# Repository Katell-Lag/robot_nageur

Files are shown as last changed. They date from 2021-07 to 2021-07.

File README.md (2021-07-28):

# Robot_nageur
Ce dépôt rassemble les codes et les documents réalisés lors du stage ingénieur d'Anna Agobian et Katell Lagattu.

Vous pourrez retrouver l'ensemble des scripts python et C, les fichiers des pièces 3D, datasheet et documentations utilisées.

Un README a été créé pour chacun des dossiers afin d'ajouter une description plus détaillée des documents disponibles.

## Décomposition du robot 

Ce robot se compose de la manière suivante : un buste (stockant l’ensemble du matériel électronique : cartes, batteries etc.) composé de 2 bras, équipé chacun de 3 articulations (une épaule, une rotation biceps et un coude), et de 2 jambes, équipée chacune d’un unique moteur. 

Au total, le robot sera composé de 9 tubes étanches (3 pour chaque bras, 1 pour le buste et 1 pour chaque jambe), d’une dizaine de cartes électroniques, d’une unique batterie. Parmi les cartes électroniques on retrouvera soit une unique BeagleBone Blue accompagnée de 3 ESC pour générer le signal PWM de nos BLDC, soit une raspberry PI3 (ou plusieurs suivant les SPI disponibles) accompagnée de 3 cartes (1pour chaque moteur du bras) trinamic TMC4671+TMC6100-BOB pour réaliser la boucle fermée et générer le signal PWM des BLDC. 
En plus de cela sera rajouté des IMU (centrales inertielles) aux biceps, avant-bras et jambes afin de s’assurer du mouvement exécuté. Elles seront alors accompagnées d’une carte STM32 permettant de traiter leurs données et de les communiquer à la carte mère.

## Aspect général du robot

Réaliser ce robot doit être fait en diverses étapes très distinctes. En effet, avant de partir sur sa construction et le tester dans l'eau il faut vérifier son mouvement, gérer l'emmêlement des fils électriques etc.
Ainsi nous avions donc défini cet aspect global de réalisation :

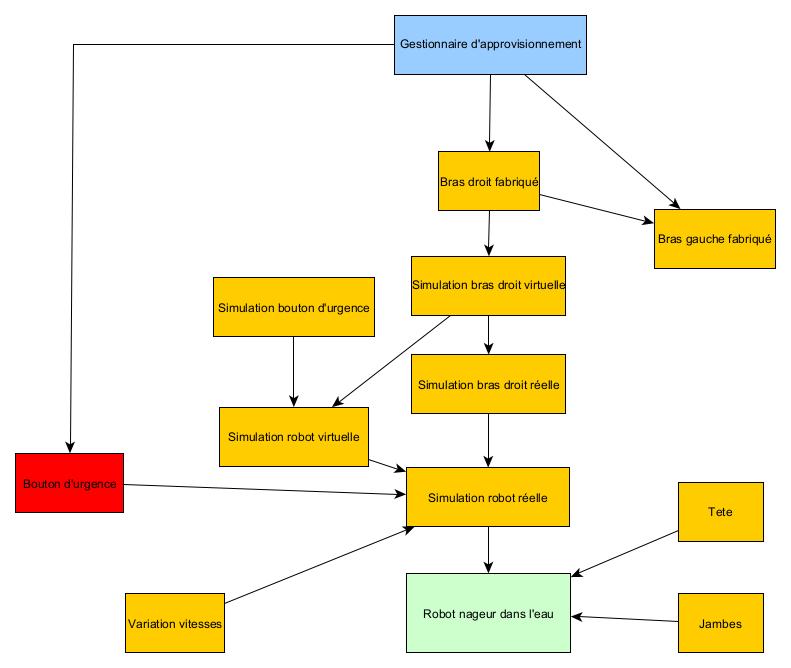
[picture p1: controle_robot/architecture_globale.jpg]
aspect général


Nous avons donc actuellement réaliser le bras gauche, simuler le bras, le robot entier en virtuel et réaliser le bouton d'urgence. Nous en étions à la réalisation du bras gauche en réel.

Pour tout renseignement supplémentaire contactez nous via les emails suivants :
##### anna.agobian@etu.umontpellier.fr
##### katell.lagattu@ensta-bretagne.org

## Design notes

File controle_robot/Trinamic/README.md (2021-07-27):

DOCUMENTATION TRINAMIC

- Avec la TMC6100-EVAL-KIT (kit de développement, utilisation de l'IDE de Trinamic)
- Avec la TMC4671+TMC6100-BOB (tentatives de connexion en SPI avec une Raspberry Pi3)

LIENS

- Github Trinamic: https://github.com/trinamic
- Site de Trinamic: https://www.trinamic.com/support/software/
- Blog de Trinamic avec des tutos: https://blog.trinamic.com/
- Chaîne youtube de Trinamic: https://www.youtube.com/user/TrinamicMC

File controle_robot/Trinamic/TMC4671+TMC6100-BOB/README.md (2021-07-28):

# UTILISATION DE LA TMC4671+TMC6100-BOB

La carte  trinamic TMC4671+TMC6100-BOB est une carte de développement permettant à l'utilisateur de prototyper des applications directes à ses moteurs. Cette carte permet de contrôler un moteur, de récupérer les données de 2 encodeurs et surtout de réaliser une boucle fermée. 
En effet, l'avantage principal de ces cartes est leur contrôle en boucle fermée. Ceci permet d'obtenir un système plus performant, plus stable et optimal: le retour des encodeurs permet d'asservir le système via un correcteur PID et d'assurer une stabilité.
Ces cartes permettent aussi de contrôler les moteurs par la commande FOC(Field-Oriented Control)- soit contrôle à flux orienté-. 

### Commande FOC

En effet, cette commande FOC- appelée également "commande vectorielle"- permet de garder une précision continue des commandes envoyées, notamment pour les moteurs BLDC (BrushLess Direct Courant). Pour se faire, c'est à partir de la consigne de vitesse du moteur que le flux et le couple nécessaire sont calculés et qu'ensuite les courants requis sont déduits. 

La commande FOC est composée de deux forces Q (quadrature) et D (direct), perpendiculaire et parallèle à l'axe des pôles du rotor. 

### Synoptique



c: type de connexion     p : nombre de ports/fils envisagés

### Ce dossier décrit nos tests pour faire fonctionner le bus SPI entre Raspberry et Trinamic.

#### REMARQUE PRELIMINAIRE:

Pour accéder à la Raspberry que nous avons utilisée, et qui contient tous nos fichiers tests:

Via un écran, aller dans /etc/wpa_supplicant/wpa_supplicant.conf et rentrer un réseau wifi et son mot de passe pour se connecter via ssh. 

user: pi

mdp: raspberry

#### BRANCHEMENTS: 

voir schéma.

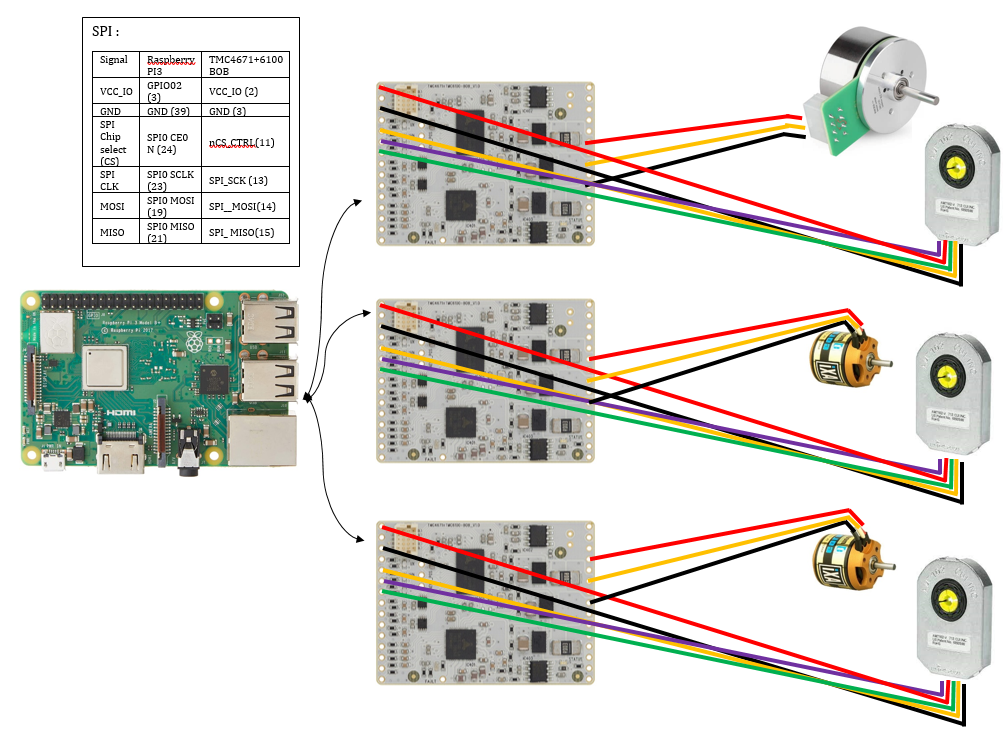
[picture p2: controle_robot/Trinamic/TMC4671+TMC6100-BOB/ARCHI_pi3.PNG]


#### CONTEXTE:

Pour contrôler les moteurs avec la TMC4671+TMC6100-BOB, il faut d'une part envoyer les bons registres à la carte, et d'autre part configurer correctement la communication SPI. Nous n'avons pas réussi à faire fonctionner le SPI, mais ce dossier rassemble nos pistes.

#### REGISTRES:

Les registres que nous avons utilisés sont: 
  - Ceux que nous avons exporté du TMCL-IDE (voir https://github.com/Katell-Lag/robot_nageur/blob/main/controle_robot/Trinamic/TMC6100-EVAL-KIT/20210706_10.24.59_TMC4671-EVAL_Settings_V1.c)
  - Ceux qui sont dans le Pytrinamic et qui fonctionnaient via USB (voir https://github.com/trinamic/PyTrinamic/blob/master/PyTrinamic/examples/evalboards/TMC4671/TMC4671_eval_BLDC_open_loop.py)

#### COMMUNICATION SPI:

Voir TMCAPI_EXAMPLE et TMCAPI_EXAMPLE2.

Ces codes sont inspirés du tuto: http://blog.trinamic.com/2018/02/19/stepper-motor-with-tmc5160/

Ce tuto explique comment relier une Raspberry Pi3 à une TMC5160-BOB.

Nous avons essayé d'adapter le code de différentes manières pour faire fonctionner la liaison avec notre carte, mais sans succès.

#### NOTES SUR LA COMMUNICATION SPI:

- Nous utilisons la librairie bcm2835 pour configurer le SPI.

- Nous avons une incertitude sur les modes des PIN (HIGH ou LOW). De plus, la carte du tuto ne possède pas les mêmes PIN que la nôtre. Par exemple, nous avons supposé qu'il ne fallait pas se soucier du CLK.

- Concernant la fonction tmc4671_readwriteByte, elle doit être présente si l'on utilise la dernière version du TMC-API. Nous ne savons pas si elle est nécessaire dans notre cas.

- Les fonctions définies dans le TMC_SPI.c sont les fonctions permettant de transmettre les données en SPI, plus précisément d'écrire dans les registres de la carte via SPI.

- Nous avons essayé de lire des données provenant de la carte avec tmc4671_ReadInt mais sans succès. Il semble que la liaison ne se fasse pas.

- Après avoir réalisé des tests grâce à un loopback test avec l'API spidev, nous avons conclu que le problème n'était pas la Raspberry elle-même: https://www.raspberrypi.org/documentation/hardware/raspberrypi/spi/README.md

- A l'oscilloscope, nous avons également pu observer que des trames étaient bien envoyées de la Raspberry vers la Trinamic. Nous pensons donc que la Trinamic ne parvient pas à interpréter ces trames.

#### AUTRES METHODES:

Nous avons aussi utilisé d'autres méthodes qui n'ont pas fonctionné non plus, peut-être parce que les cartes utilisées dans ses librairies ne sont pas les mêmes: voir test_levref (à partir de https://github.com/trinamic/PyTrinamic/commit/4e6927a0448545c5d8767285cda3d14c63dbb35c) et tripipy (à partir de https://github.com/pootle/tripipy).

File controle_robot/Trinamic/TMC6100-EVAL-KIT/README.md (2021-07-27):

# UTILISATION DE LA TMC6100-EVAL-KIT (VIA TMCL-IDE ET CODE PYTHON).

## PRESENTATION:

La TMC6100-EVAL-KIT est composée d'un microcontrôleur Landungsbrücke, deux cartes de liaisons Eselsbrücke, une carte "motion controller" TMC4671-EVAL et une carte driver TMC6100-EVAL. L'intérêt d'utiliser une telle carte par rapport à une BeagleBone est qu'elle est capable de contrôler un moteur BLDC en boucle fermée, aussi bien en couple qu'en position.

## TMCL-IDE:

On accède au TMCL-IDE via usb. Il se télécharge à partir du lien suivant : https://www.trinamic.com/support/software/tmcl-ide/ 

Cet IDE a été conçu par TRINAMIC afin de simuler à partir d'une fenêtre "*wizard*" le comportement du moteur en sortie. En effet, il permet de visualiser en direct le comportement du BLDC en fonction des encodeurs, ou "sensors hall", de modifier les paramètres PI du correcteur et également ceux du moteur lui-même. Il est également possible de changer le firmware de la Landungsbrücke afin d'y entrer par défault les paramètres souhaités. Cependant, nous n'avons actuellement pas réussi à réaliser cette action correctement.

*EXEMPLE : Pour faire tourner un des moteurs BLDC: aller dans Wizards et entrer les paramètres visibles dans les captures d'écran du dossier robot_nageur/controle_robot/Trinamic/TMC6100-EVAL-KIT/Setup
La boucle fermée fonctionne, ainsi que le FOC (Field Oriented Control).* 

## BRANCHEMENTS: 

voir schéma
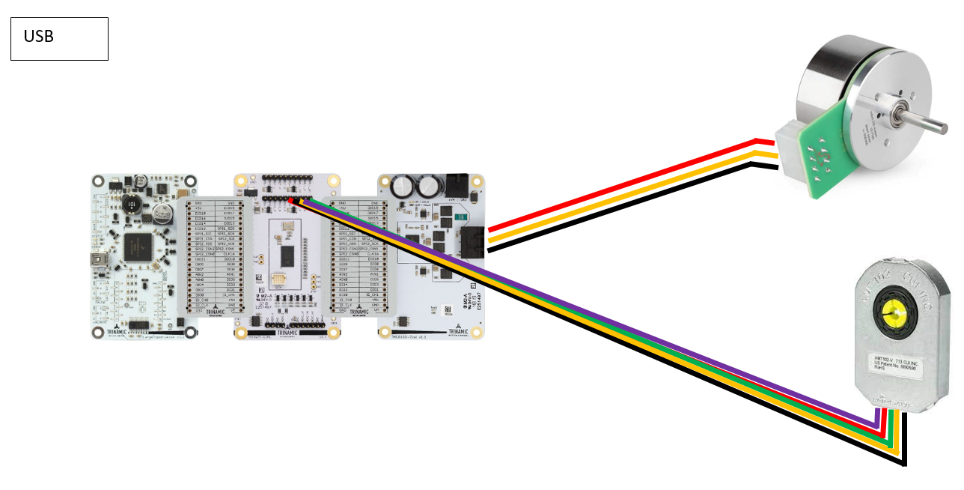
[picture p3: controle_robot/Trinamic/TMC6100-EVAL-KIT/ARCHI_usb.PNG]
branchement usb


## DOCUMENTS UTILES

* Manual : https://www.trinamic.com/fileadmin/assets/Support/Software/TMCL_reference.pdf

* Tuto de Trinamic pour la configuration Wizard: https://blog.trinamic.com/2020/02/25/driving-a-linear-stage-with-the-tmc4671/

* Tuto en vidéo de la configuration Wizard: https://www.youtube.com/watch?v=g2BHEdvW9bU&t=32s

## LIEN GITHUB VERS CODE PYTHON FONCTIONNEL:

Sans passer par l'IDE mais en exécutant un code python avec une liaison USB, nous arrivons à faire tourner le moteur en boucle ouverte.
Ce code fonctionne avec une connexion usb, soit entre la Trinamic et un PC, soit entre la Trinamic et une Raspberry.

https://github.com/trinamic/PyTrinamic/blob/master/PyTrinamic/examples/evalboards/TMC4671/TMC4671_eval_BLDC_open_loop.py

###### NOTES:

- Si le voyant rouge de la carte s'allume, double cliquer sur Landunsbruecke puis décocher et recocher "enable drivers". Pour éviter qu'il s'allume, il faut décocher cette case avant d'alimenter les moteurs, puis la recocher.
- Nous avons essayé de changer directement le firmware en suivant le tuto: https://blog.trinamic.com/2020/02/28/driving-a-linear-stage-with-the-tmc4671-firmware-adaptation/ mais cela a fait planter la carte. Si jamais cela arrive, il suffit de court-circuiter id_clk et id_ch0, puis de redémarrer/rebrancher la carte. On peut alors remettre l'ancien firmware disponible sur le site de Trinamic.
- Le "direct mode" qui permet de contrôler le moteur sans passer par le Wizard fonctionne: https://blog.trinamic.com/2020/02/26/driving-a-linear-stage-with-the-tmc4671-controller-tuning/

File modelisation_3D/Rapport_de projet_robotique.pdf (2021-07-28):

Ecole Polytechnique Universitaire de Montpellier, Département micro-électronique et automatique
Place Eugène Bataillon, 34095 Montpellier | 1 / 30

## ROBOTIQUE MOBILE S8 – MEA4

## Année scolaire 2020-2021

## ″Projet : Modélisation, conception et réalisation d’un robot nageur″

Etudiants : Anna AGOBIAN, Tatiana DEWILDEMAN,

## Théo LEMAIRE, Paul MASSON

## Encadrants : René ZAPATA, Éric DUBREUIL, Lionel LAPIERRE

SOMMAIRE

## 1 INTRODUCTION

Ce document est un rapport du travail effectué dans le cadre des projets de robotiques mobiles au S8 en MEA4.

### 1.1 Contexte

Le but de ce projet est de développer un robot humanoïde nageur (crawl et/ou papillon). Celui-ci doit être capable de se déplacer et de s’orienter dans un environnement ouvert et agité comme la mer. Afin de s’orienter, celui-ci comportera une tête, déjà développée, utilisant un algorithme de perception des bouées jaunes.

### 1.2 Attentes

Modélisation, conception et réalisation d’un robot nageur. Le travail consiste à étudier les modèles de nage d’un robot nageur (crawl et/ou papillon), de réaliser des simulations (à partir d’outils existants), de réaliser une maquette de bras, d’effectuer une recherche internet sur des moteurs qui pourraient être adéquats et enfin, de réaliser un robot réel (échelle de 1/2 ou 1 à préciser).

## 2 MODELISATION

### 2.1 Adaptation du bras humain

Le bras humain est constitué de 5 degrés de liberté :
- Rotation principale de l’épaule a1
- Écartement de l’épaule du corps a2
- Rotation axiale de l’épaule a3
- Pliement du coude a4
- Rotation axiale de l’avant-bras a5

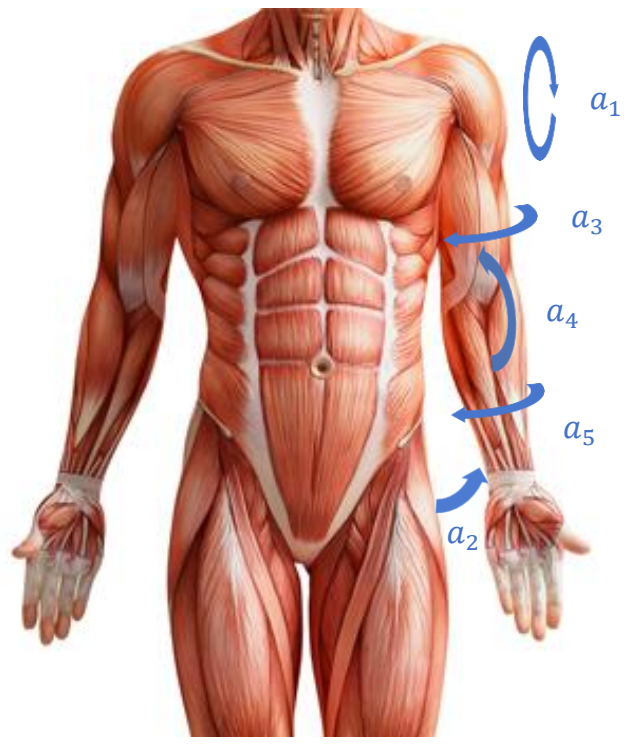
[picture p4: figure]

Figure 1: Illustration des degrés de liberté du bras humain

A chacun de ces degrés de liberté est associé une articulation, générant une complexité de modélisation non négligeable. Cependant, lors d’un mouvement de nage tel que le crawl, seuls les articulations a1, a3 et a4 sont indispensables. Par soucis de simplicité, nous nous limiterons donc à ces 3 degrés de liberté.

### 2.2 Détermination du mouvement

Afin de déterminer le mouvement du bras lors de la nage du crawl, nous utilisons le simulateur MATLAB, nommé KynProfile, permettant de contrôler un bras simplifié aux 3 degrés de libertés précédemment évoqués.

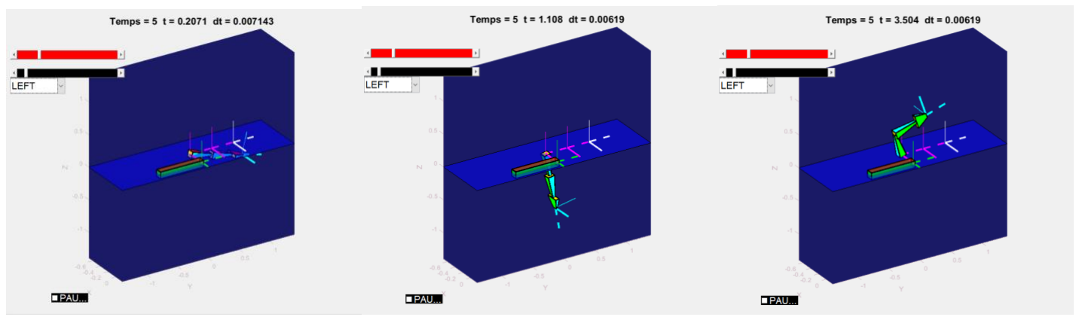
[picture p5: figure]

Figure 2: Illustrations du simulateur KynProfile

Ce simulateur prend en entrée les commandes angulaires de chaque articulation. Afin de former ces commandes, nous utilisons un 2ième simulateur, nommé Deform_Splines.

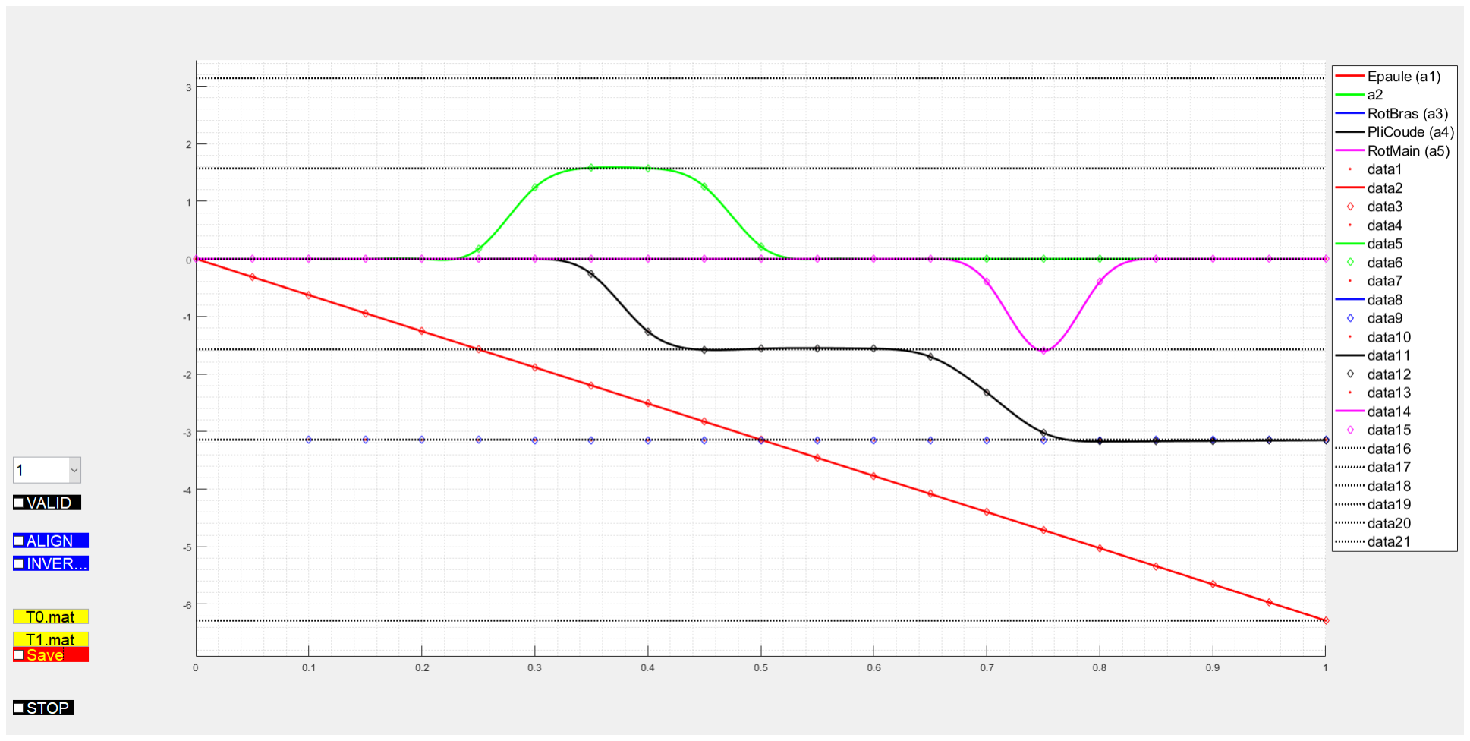
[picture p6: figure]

Figure 3: Illustration du simulateur Deform_Splines

Celui-ci nous permet de manier les trajectoires angulaires de chaque articulation. L’axe des abscisses représente une période, ici un mouvement de crawl, tandis que l’axe des ordonnées représente la position angulaire de l’articulation. Il est donc important que chacune des articulations en x = 1 se retrouve à sa position initiale ± 2π pour garantir la continuité du mouvement entre chaque période.

Grâce à ces 2 simulateurs, nous avons décomposé un mouvement de crawl en un enchaînement de mouvements élémentaires et faisables avec les 3 articulations :

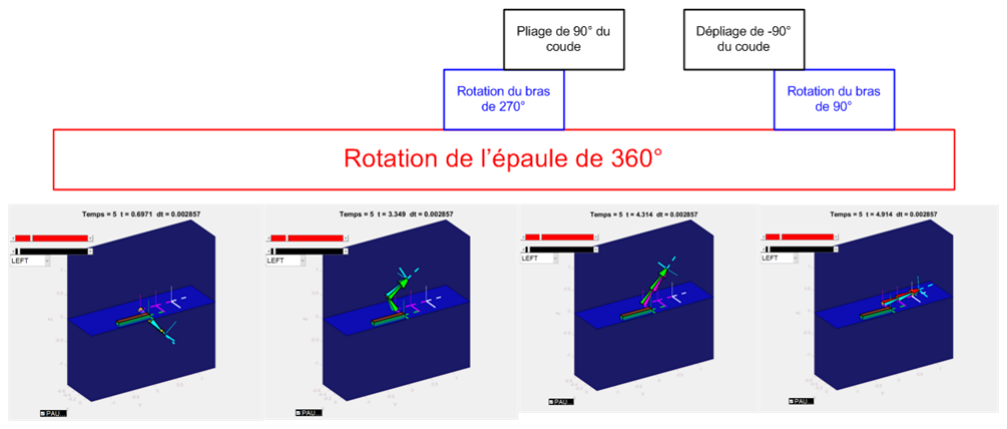
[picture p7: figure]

Figure 4: Enchainement des mouvements lors du crawl

Cet enchaînement se traduit par les trajectoires angulaires suivantes :

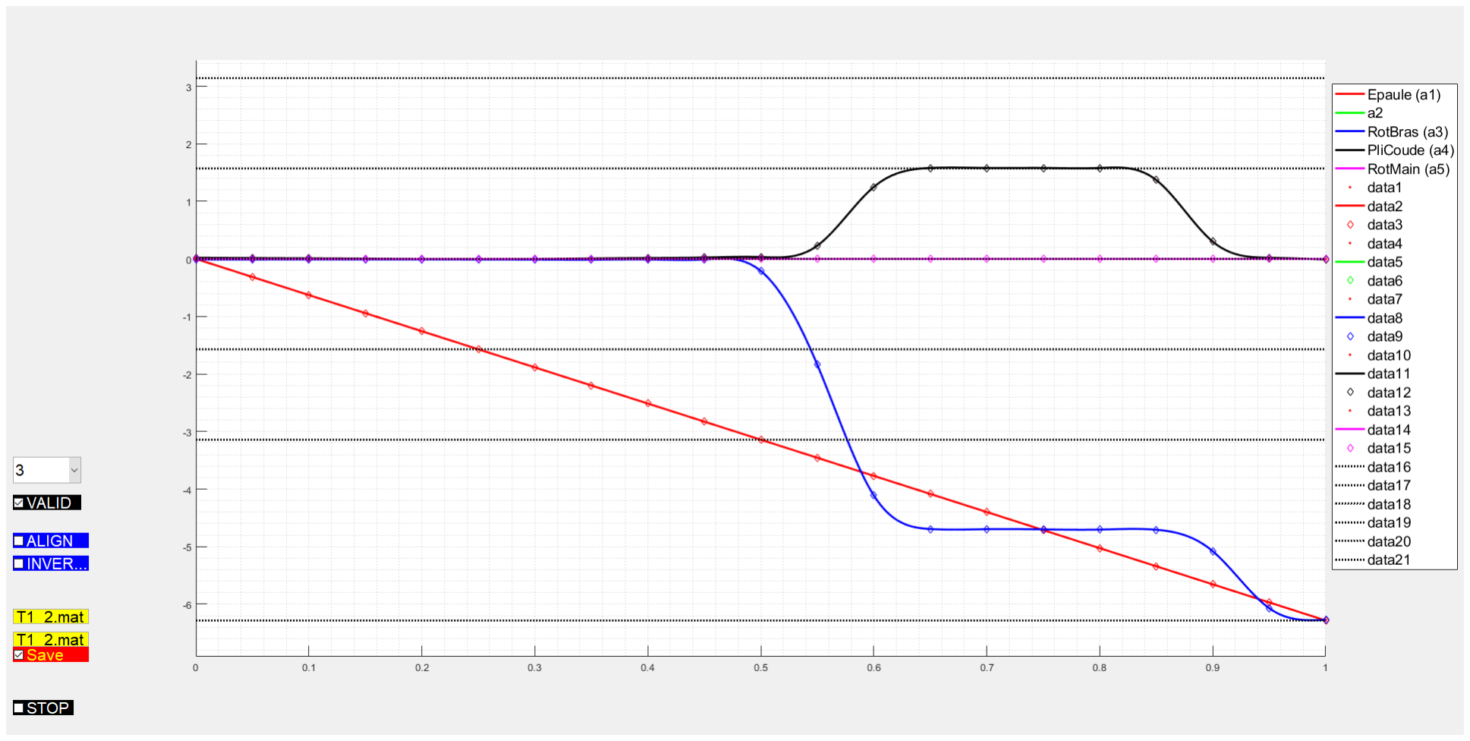
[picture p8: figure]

Figure 5: Trajectoires angulaires de a1, a3 et a4 lors d’un mouvement de crawl

### 2.3 Extraction des commandes et choix du type des moteurs

Une fois le mouvement du crawl vérifié et validé sur simulateur, nous avons pu extraire les trajectoires de chacune des articulations et en déduire les moteurs que nous allons utiliser :
- Rotation continue sur a1 Þ utilisation d’un moteur CC avec un encodeur pour asservir en position.
- Enchaînements de rotations de 90° ou 270° sur a3 Þ utilisation d’un moteur CC avec un encodeur pour asservir en position.
- Enchaînements de rotations de 90° dans les 2 sens sur a4 Þ utilisation d’un servo moteur.

Toutes les positions des 3 trajectoires ont été enregistrées dans un fichier CSV afin de pouvoir les utiliser avec l’algorithme de commande.

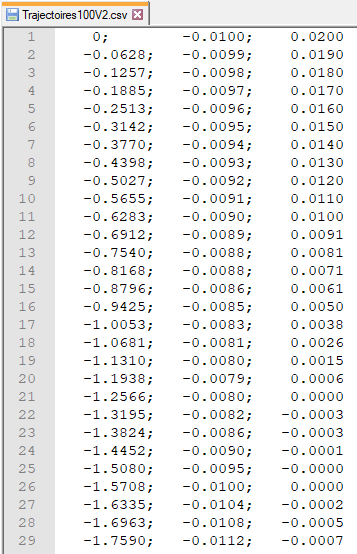
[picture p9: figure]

Figure 6: Début du fichier CSV des positions

### 2.4 Réalisation de la maquette

Afin de confirmer notre modèle théorique, nous avons réalisé une maquette du bras. Pour correspondre au modèle simplifié précédemment explicité, celle-ci est constituée de 4 parties :
- Un buste
- Une épaule
- Un bras
- Un avant-bras avec une main

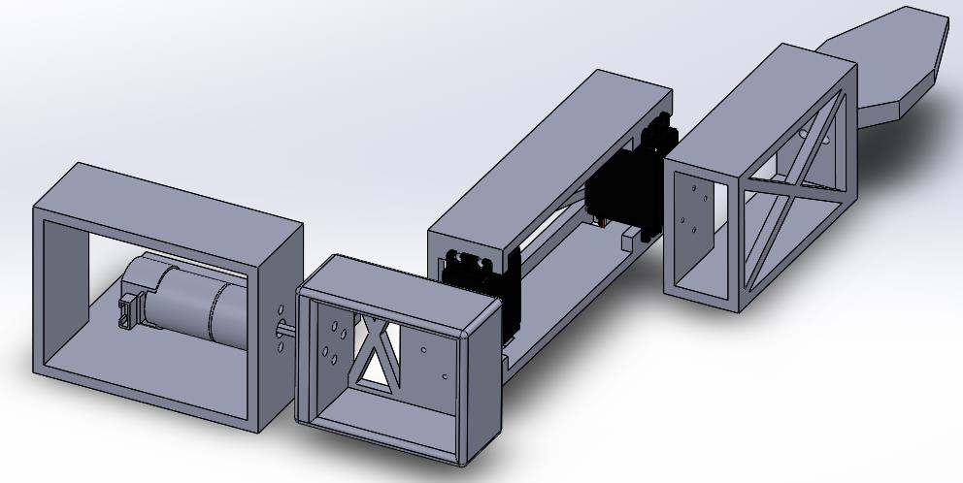
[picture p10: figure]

Figure 7: Maquette du bras – 1

ère version

La Figure 7 représente la première version de la maquette. Celle-ci est constituée d’un moteur CC avec encodeur et de 2 servos moteurs. Cependant, lors des tests avec celle-ci, nous nous sommes rendu compte que l’articulation a3 devait pouvoir faire une rotation de 360°. En effet, pour éviter que les fils des moteurs ne s’enroulent autour du bras lors de son mouvement, nous sommes dans l’obligation d’effectuer une rotation complète sur a3, mouvement impossible pour un bras humain. Or, un servo moteur est limité à 180°. C’est donc pour cette raison que nous avons choisi d’utiliser un moteur CC à cette position.

Une fois cette contrainte identifiée, les pièces de l’épaule et du bras ont été modifiées pour donner le modèle suivant :

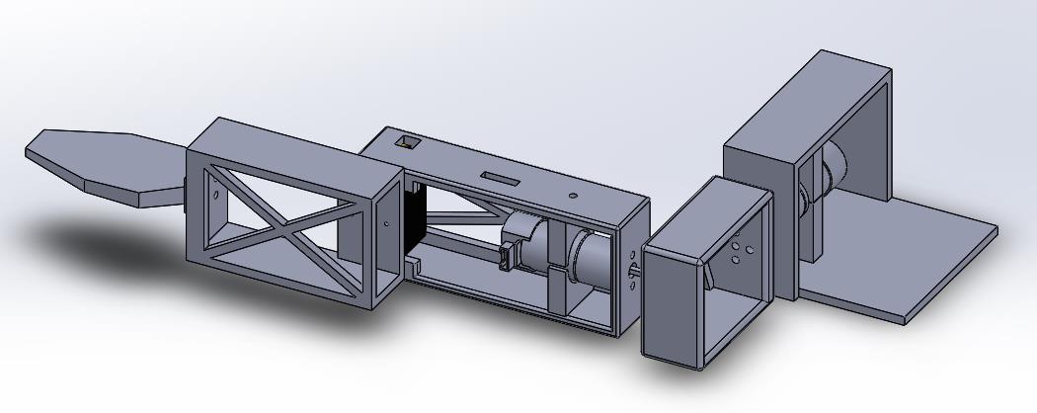
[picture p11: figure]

Figure 8: Maquette du bras – 2

ième version

Etant donné le faible couple que possède notre moteur CC responsable de la rotation de l’épaule (articulation a1), nous avons été contraints de rajouter un jeu d’engrenages. Ainsi, la liaison entre le buste et l’épaule se fait maintenant grâce à 2 engrenages (80 dents et 16 dents) multipliant le couple par 5.

### 2.5 Modélisation du robot à l’échelle 1:1

### 2.5.1 Modélisation du corps

Pour pouvoir embarquer l’électronique nécessaire (Cf. partie 3.1 & 4) au bon fonctionnement du robot, nous devons utiliser des tubes de plexiglas hermétiques. Afin de former un corps fonctionnel, il est important de correctement agencer les tubes et de les unir. Pour cela, nous avons opté pour la solution suivante :

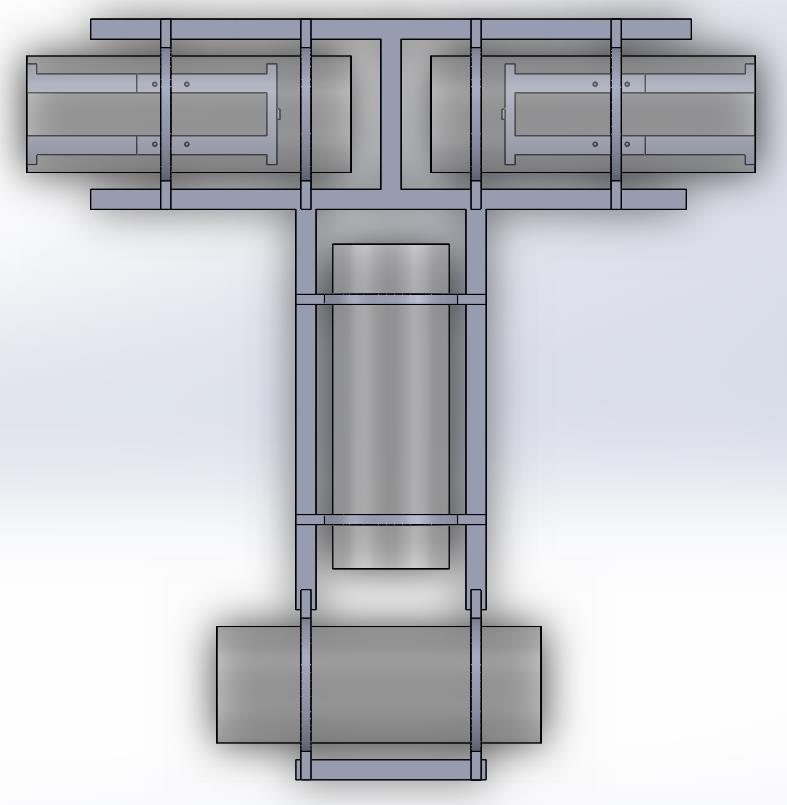
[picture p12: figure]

Figure 9: Corps du robot à l’échelle 1:1

Comme l’indique la Figure 9, les tubes ont été placés de telle sorte à former un buste à la géométrie similaire à celle d’un buste humain :
- 2 tubes pour les épaules
- 1 tube pour le tronc
- 1 tube pour les hanches

Tous les éléments sont reliés par un squelette et y sont attachés grâce à des demi-cercles emprisonnant les tubes et se fixant au squelette.

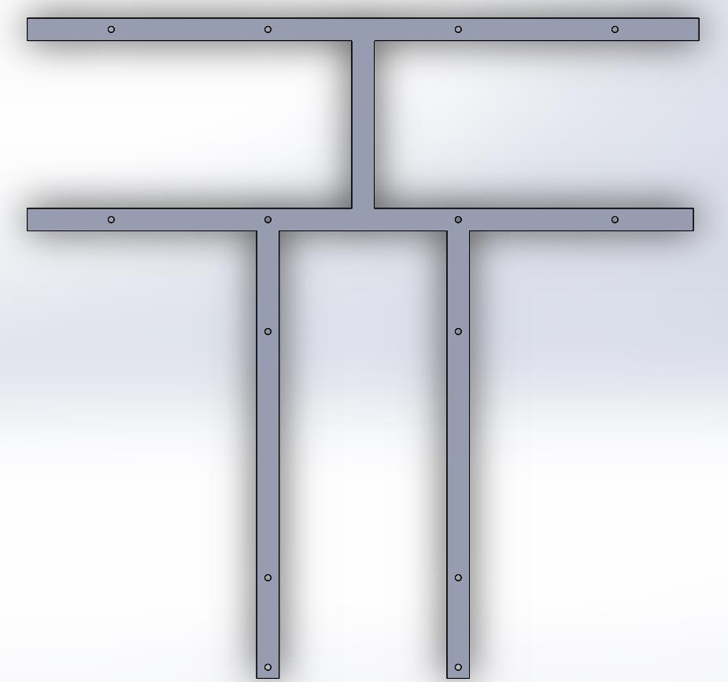
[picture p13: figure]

Figure 10: Squelette du robot

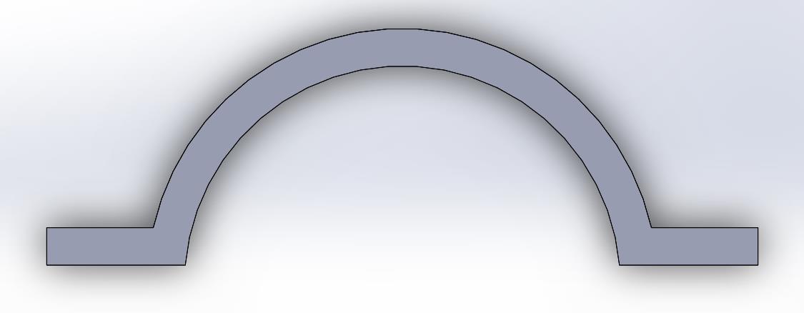
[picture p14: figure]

Figure 11: Attache emprisonnant les tubes

Le buste du robot fait donc 728mm de large pour 760mm de hauteur. Ces dimensions sont plus importantes que celles d’un buste humain, surtout pour la largeur d’épaules. Cependant, cela augmente sa surface et, par la même occasion, sa flottabilité. S’il s’avère que le robot flotte trop, affectant ainsi son fonctionnement, il suffira de le lester.

Afin de garantir une solidité suffisante, nous avons découpés ces pièces à la CNC, dans des plaques de plexiglas de 1cm d’épaisseur.

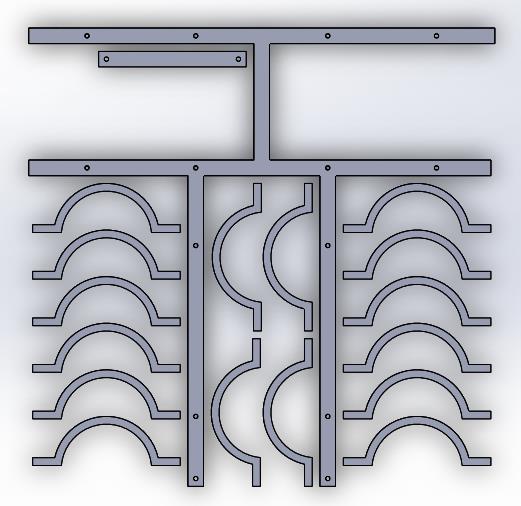
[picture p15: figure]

Figure 12: Disposition des pièces pour une découpe à la CNC

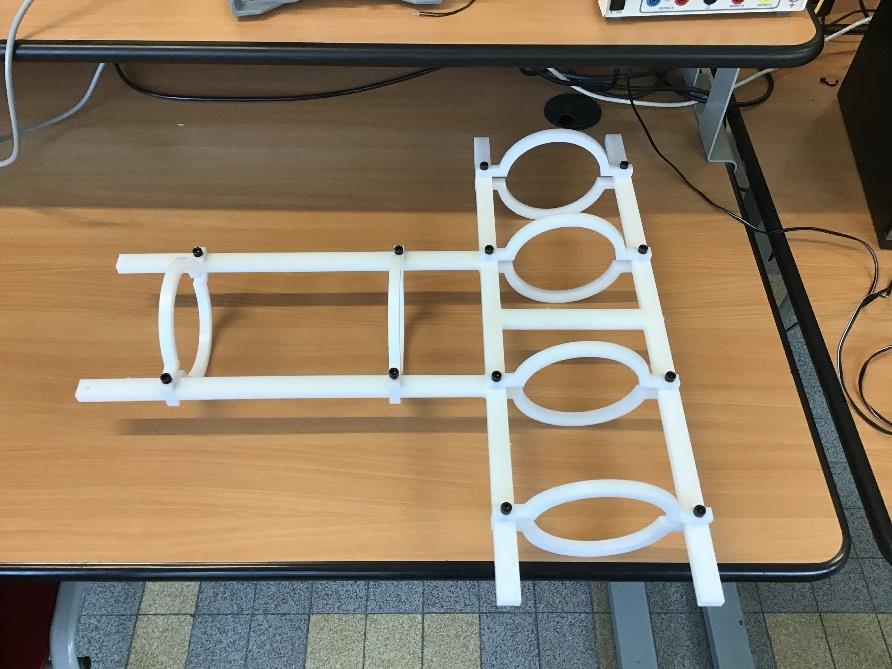
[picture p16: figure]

Figure 13: Aperçu des pièces découpées et assemblées

### 2.5.2 Modélisation interne aux tubes

En attendant de recevoir les différents tubes hermétiques, nous avons créé les différents systèmes de fixation des composants à l’intérieur. Les dimensions nécessaires à cette modélisation ont été prise sur un tube issu d’un autre projet.

Pour la fixation des moteurs, nous avons, dans un premier temps, pensé à faire une plaque qui pouvait se fixer de part et d’autre du tube pour garantir sa solidité. En effet, le moteur est lourd et envoie beaucoup de puissance, il fallait donc trouver un système qui permettait de bien le maintenir. Après mure réflexion, nous avons opté pour un système de maintien sur un côté seulement et de l’autre côté, des barres qui viennent s’appuyer contre les parois du tube. La pièce a été conçue afin de faire sortir l’arbre moteur au centre du tube.

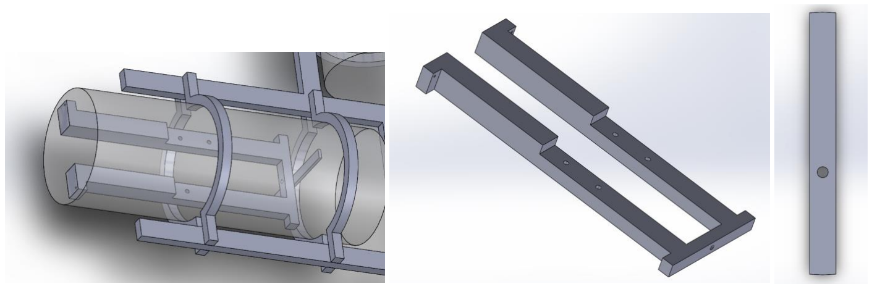
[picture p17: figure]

Figure 14: Attaches internes aux tubes

Enfin, pour garantir le support de la carte responsable de la commande des moteurs, nous avons modélisé et imprimé en 3D une dernière pièce venant se fixer sur des trous taraudés déjà existants à l’intérieur des tubes.

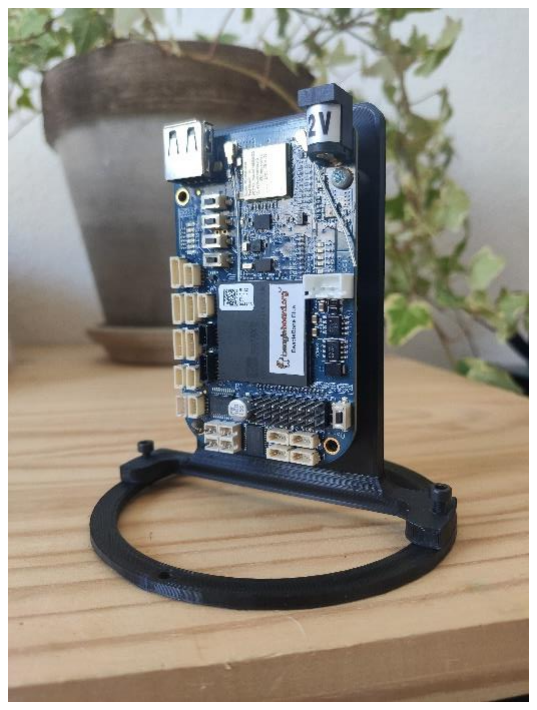
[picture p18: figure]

Figure 15: Attache de la carte

### 2.5.3 Modélisation du bras

Etant donné le poids et le couple à appliquer (Cf. partie 4.1.1), nous avons cherché une épaisseur suffisante de matériaux pour assurer la solidité du robot. Pour cela, nous avons choisi une épaisseur de 3cm. Pour des raisons similaires à précédemment, les pièces sont vouées à être découpées à la CNC dans des plaques de 1cm puis assemblées.

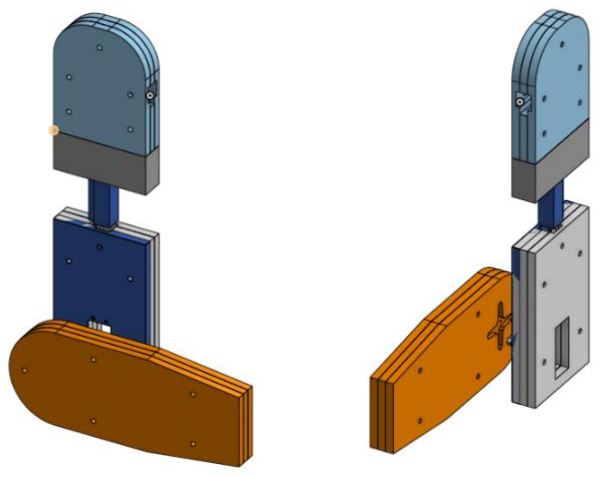
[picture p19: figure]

Figure 16: Modèle du bras assemblé (sans les moteurs)

Chacune des pièces possède des encoches et emplacements correspondants, respectivement, à l’arrivée d’axes et à l’emplacement de moteurs à intégrer au bras.

## 3 PROGRAMMATION

### 3.1 Partie hardware

Concernant l’architecture hardware, nous avons fait dans un premier temps le choix de travailler sur une Beagle Bone Blue. En effet, celle-ci dispose d’un panel de ports :
- GPIO
- Connecteurs pour servos moteurs
- Connecteurs pour moteurs CC avec encodeur
- Etc…
Ils nous permettent de travailler directement avec les moteurs que nous avons sélectionnés (Cf. partie 2.3) sans qu’il soit nécessaire d’ajouter de composants externes. Nous obtenons donc l’architecture suivante :

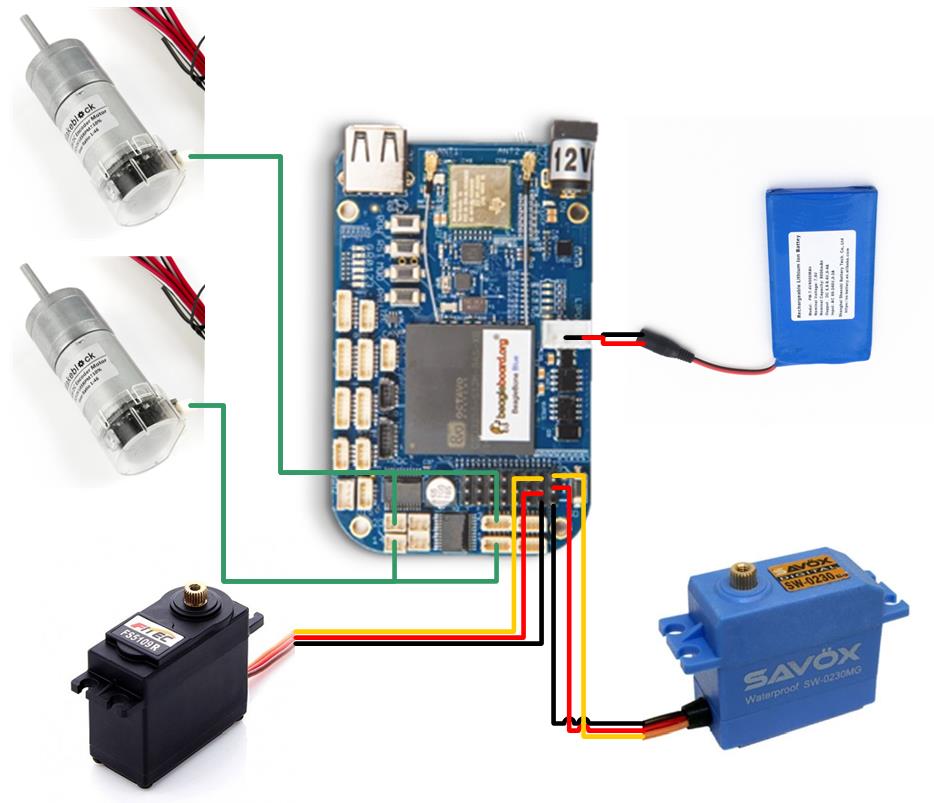
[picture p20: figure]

Figure 17: Architecture hardware de la maquette

Comme évoqué précédemment, nous utiliserons des moteurs CC avec encodeur pour le bras et pour l’épaule, un servo pour l’avant-bras et un pour la jambe. Nous verrons par la suite qu’il sera nécessaire de modifier ces moteurs pour s’adapter à la structure du robot (moteurs étanches, couples suffisants, etc…). De même, pour la batterie qui devra être changée en conséquence.

Le choix de la Beagle Bone Blue a également été fait pour sa possibilité de programmation en wifi. Ainsi, nous pouvons continuer à coder les dernières modifications sans nécessairement ouvrir les tubes hermétiques du système final.

### 3.2 Partie Software

### 3.2.1 Environnement de programmation

Afin d’accéder et avoir une meilleure gestion des fichiers sous la Beagle Bone Blue, nous travaillons avec WinSCP. Concernant la compilation et l’exécution des programmes, nous utilisons PuTTY par simplicité. Les Figure 15 et Figure 16 permettent donc de comprendre la structure de l’environnement.

Figure 18: Identification de la carte

Connection Wifi :
Identifiant | BeagleBone – XXX
Mot de passe | BeagleBone

Accès via Terminal /Putty/Winscp/… :
Adresse IP | 192.168.8.1
Identifiant | debian
Mot de passe | temppwd

Figure 19: Exécution du programme

Le paramètre ‘1’ passé à l’exécutable permet la bonne exécution du code, nous verrons par la suite son utilité et le rôle d’autres paramètres.

Pour accéder au fichier et modifier le programme, voici les étapes :

Chemin d’accès au projet | /home/debian/rc_project_nageur/

Vue d’ensemble

Description | Quelques exemples de mouvements générés dont les trajectoires et le nombre d’échantillons varient
| Fonction de commande d’un servo moteur à rotation continue (pas utilisé dans notre prototype)
| Fonction de commande d’un servo moteur prenant une commande en radians
| Main et autres fichiers
| Fonction de commande d’un moteur DC avec encodeur, prend donc en entrée une vitesse en radians/s
Figure 20: | Étapes pour accéder aux fichiers et les modifier

Sous PuTTY ou un terminal :
Identifiant | Debian
Mot de passe | temppwd
Commandes | cd rc_project_nageur
| sudo
| ./rc_project_nageur 1
Mot de passe | temppwd

### 3.2.2 Fonction de base

Les fichiers Dc.c, Servo.c et ServoContinue.c permettent de contrôler leurs moteurs respectifs. Voici une brève description de ces derniers :

Fonctions | Description
int Dc(double DC1_VITESSE, double DC1_PORT) | Envoie une commande en rad/s au port désiré allant de 1 à 4. Mettre ‘5’ pour envoyer la commande à tous les ports.
int Servo (long double S1_ANGLE_RAD, double S1_Hz, double S1_PORT, double S1_DELAY) | Envoie une commande d’angle entre 0 et π radians aux moteurs (S1_ANGLE_RAD), avec une fréquence de commande désirée (S1_Hz conseillée à 50Hz), au port désiré et avec un délai voulu. Le délai peut être utilisé pour rendre la fonction bloquante. Si pas nécessaire, mettre 1.
int ServoContinue (long double S1_ANGLE_RAD, double S1_Hz, double S1_PORT, double S1_DELAY) | Même description que précédemment sauf qu’ici S1_ANGLE_RAD est une vitesse angulaire car un servo à courant continu ne se commande pas en position mais en vitesse.
Figure 21: | Description des commandes des moteurs

Ces fonctions sont inspirées de la librairie fournie sur la Beagle Bone Blue. D’autres paramètres peuvent être ajoutés et nécessaires selon les moteurs en question : tension de commande, pulse, etc…, ces derniers étant déjà dans les fichiers mais laissés à des valeurs par défaut.
C’est donc sur la base de ces fonctions que nous allons pouvoir commander nos moteurs et générer notre trajectoire.

### 3.2.3 Fonctions de contrôle et de génération de trajectoire

Plusieurs fonctions de contrôle des moteurs ont été réalisées. Toutes ne sont pas nécessaires pour l’architecture de commande que nous avons choisie mais pourrait l’être pour une version ultérieure ou l’ont été pour avancer dans notre réflexion.

Fonctions | Description
int LectureCsv(void); [Utilisée] | Permet de lire les trajectoires accessibles dans un fichier CSV issu de MATLAB et de stocker chaque colonne dans un tableau : Colonne 1 Þ traj1 (positions de l’épaule) Colonne 2 Þ traj2 (position du bras) Colonne 3 Þ traj3 (position de l’avant-bras)
int Dc_Bras(int DC_PORT, double DC_TEMPS_DEPART, double DC_TEMPS_BOUCLE, int DC_POSITION_DEPART); | Commande du moteur DC du bras en fonction du temps et utilisant les différents plateaux des trajectoires comme paliers à atteindre.
int Dc_Bras_pos(int DC_PORT, double DC_POSITION_EPAULE_DEPART, double DC_POSITION_DEPART_BRAS); [Utilisée] | Commande du moteur DC du bras en fonction de la position de l’épaule et utilisant les différents plateaux des trajectoires comme paliers à atteindre. Nous faisons ici un asservissement en position du moteur DC du bras pour vérifier sa précision.
int Dc_Trapeze(int DC_PORT, double DC_POSITION_EPAULE_DEPART, double | Commande en trapèze 1/3, 1/3, 1/3 en fonction du temps.

DC_TEMPS_DEPART, double DC_TEMPS_BOUCLE, double DC_POSITION_EPAULE_DESIRE);

int Dc_Bras_Trapeze(int DC_PORT, double DC_POSITION_EPAULE_DEPART, double DC_POSITION_DEPART_BRAS, double COMPTEUR_TOUR); [Utilisée] | Séquence de commande en trapèze du bras pour générer le mouvement final. Chaque commande interne est faite avec un trapèze en position.
nt Dc_Trapeze_pos(int DC_PORT, double DC_POSITION_DEPART, double DC_POSITION_DESIRE, double DC_VITESSE_PLATEAU); [Utilisée] | Commande en trapèze en position avec asservissement.
int Servo_Jambe(int SERVO_PORT_JAMBE, int DC_EPAULE_PORT, int DC_POSITION_DEPART_EPAULE); [Utilisée] | Séquence de battements de jambe cadencés sur la rotation du bras : 2 battements par rotation.
int Initialisation(void); [Utilisée] | Initialisation des moteurs pour envoi de commande.
int End(void); [Utilisée] | Boucle infinie de fin de programme.
Figure 22: | Fonctions de contrôle et de générations de trajectoire

A partir de quelques-unes de ces fonctions, nous allons donc pouvoir commander le mouvement du bras complet.

### 3.3 Algorithmie et implémentation

### 3.3.1 Choix de l’algorithme

Le robot nageur est un robot se déplaçant dans un environnement incertain. En effet, plusieurs erreurs peuvent être dues à son implémentation en mer : vagues, vent, etc… En conséquence, nous avons fait le choix d’exclure tout algorithme basé sur le temps. Ainsi, les commandes en trapèze en temps sont remplacées par des commandes en trapèze en position. De ce fait, il n’y a pas une accélération pendant 1/3 du temps total de la commande mais pendant 1/3 de la trajectoire. De cette manière, nous pourrons réaliser un asservissement en position de chaque moteur plus aisément.

De plus, pour sécuriser davantage le fonctionnement de ce système, nous avons fait le choix de synchroniser nos moteurs pour qu’il n’y ait pas de déformation du mouvement du bras. En effet, le bras étant constitué de 3 moteurs soumis à des forces différentes, chaque moteur peut donc avoir un certain retard (dû à ces contraintes) ou même une certaine avance (accélération due au mouvement circulaire). Nous remarquons rapidement que le mouvement du bras est cadencé par la vitesse de rotation de l’épaule. Ce phénomène de dépendance se retrouve notamment sur les autres moteurs, formant la hiérarchie de contrôle suivante :

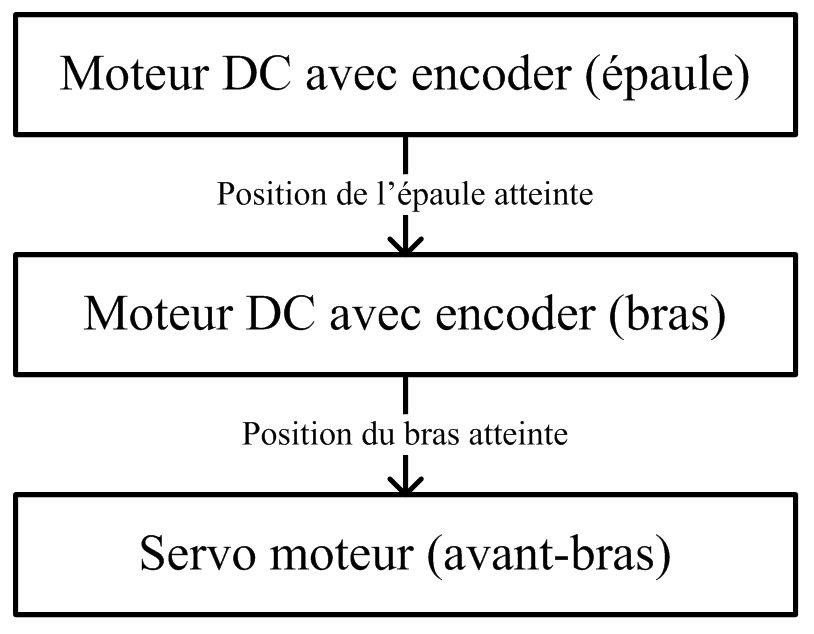
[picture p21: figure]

Figure 23: Hiérarchie d’asservissement

C’est sur cette hiérarchie que se base notre algorithme. A cela s’ajoute l’étude préalable faite sur MATLAB générant les positions de chaque moteur. Par analyse de ces trajectoires, on en déduit un découpage de la commande.

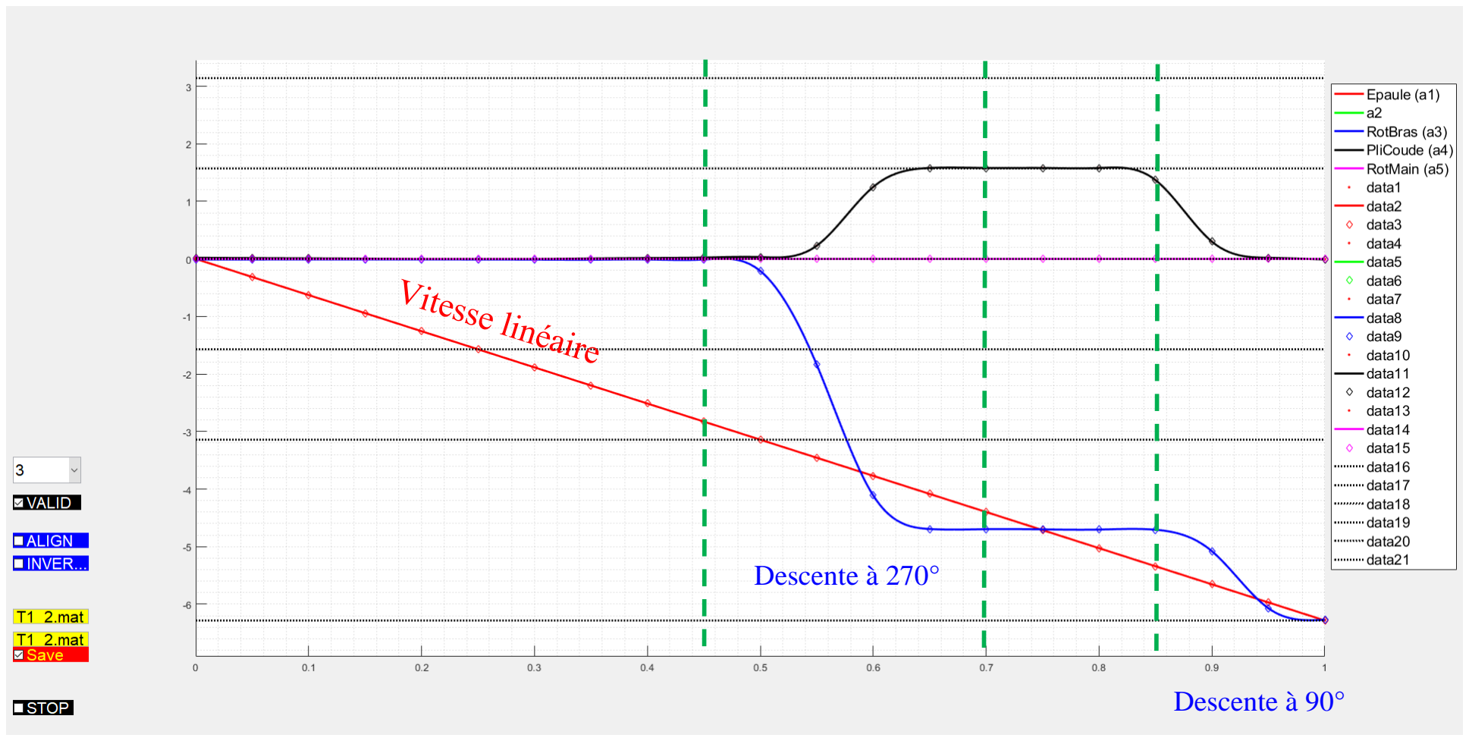
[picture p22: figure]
Descente à 270°; Descente à 90°

Figure 24: Découpage de la commande

De ce découpage en découle les étapes de commandes suivantes :

Epaule | Commande en vitesse angulaire constante
Bras | Conditions initiales : θbras = 0, θépaule = 0, θavant−bras = 0 Si θépaule < 0.45 ∗ 2π alors Vbras = 0 Sinon, si θépaule < 0.70 ∗ 2π alors Vbras = V1 Sinon, si θépaule < 0.85 ∗ 2π alors Vbras = 0 Sinon Vbras = V2
Avant-bras | Commande par lecture du fichier CSV contenant les trajectoires. Puisque le fichier comprend 100 échantillons par articulation, la position de l’avant-

bras sera actualisée tous les 1% du mouvement global. Une telle précision n’est pas forcément nécessaire.
Figure 25: Étapes de commande

### 3.3.2 Implémentation

Pour contrôler le mouvement du bras nous pouvons jouer sur quelques paramètres de commande.

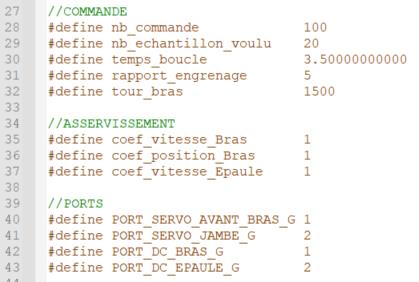
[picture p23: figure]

Figure 26: Paramètres de commande

- nb_commande : le nombre de lignes du fichier CSV sélectionné.
- nb_echantillon_voulu : sert à augmenter ou diminuer la précision de l’avant-bras. Ici, entre 10 et 20 échantillons suffisent.
- temps_boucle : il s’agit du temps que met l’épaule pour faire une rotation complète. Ainsi, nous jouons sur la vitesse de nage. Il faut cependant souligner que si le temps est trop rapide, le mouvement ne sera pas esthétique et bien formé. En effet, les moteurs n’auront pas tous le temps de bien faire leurs commandes en trapèze. Par expérimentation, on notera un temps minimal de 1.5s conseillé avec ce prototype. A l’opposé, si le mouvement est trop long, le moteur peut parfois manquer de couple et donc avoir du mal à finir sa boucle.
- coef_vitesse_Bras, coef_position_Bras, coef_vitesse_Epaule : nous avons également rajouté des coefficients s’il est nécessaire d’ajuster la vitesse de certains moteurs. Dans notre cas, comme il n’y a pas de perturbation extérieure, il n’est pas nécessaire de les modifier.

Concernant le code, nous obtenons donc l’architecture de commande suivante :

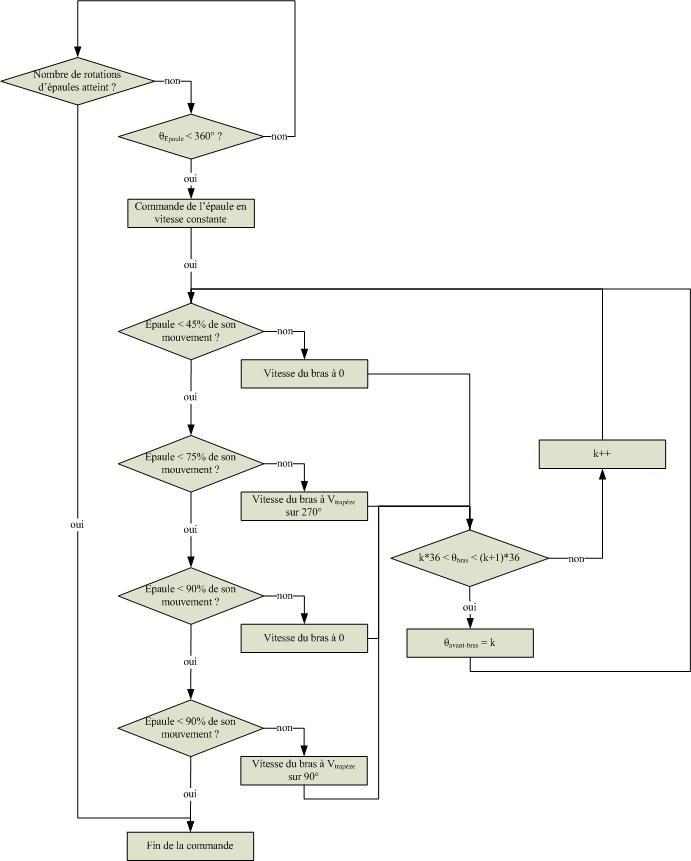
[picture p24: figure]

Figure 27: Architecture de commande

En définitive, il est donc possible de commander le mouvement de crawl d’un robot nageur avec la méthode proposée. Par ses asservissements successifs, elle garantit la préservation du mouvement d’un point de vue fonctionnel et visuel. Voici le rendu de la méthode proposée :

https://youtu.be/kqU7eqa2u2k

Figure 28: Lien vers une démonstration

## 4 IMPLEMENTATION

### 4.1 Tests du moteur pour l’épaule

En parallèle des 2 parties précédentes, nous avons cherché quels moteurs utiliser sur le modèle à l’échelle 1:1. Étant donné le type de robot à créer (forme, poids et taille proches de ceux d’un humain) et l’environnement dans lequel celui-ci va évoluer (eau de mer), il nous faut disposer de moteurs assez puissants et possédant un couple suffisant pour assurer le bon déplacement du robot. Pour cela nous avons donc étudié et testé divers moteurs.

Dans un premier temps, après avoir démonté un moteur brushless d’une patte du REX, nous avons cherché à connaître le couple qu’il peut déployer. Nous avons effectué différents tests et avons développé un système de maintien du moteur. Pour cela, nous avons utilisé une carte Beagle Bone Blue.

Un moteur brushless est un moteur composé de bobines qui sont alimentées de façon séquentielle, c’est-à-dire que le champ magnétique créé entre les bobines se déplace à la même fréquence que la tension d’entrée. Ainsi il faut donc modifier constamment la tension d’entrée afin de s’assurer que le champ soit en avance sur la position du rotor qui cherche à s’orienter dans le même sens que le champ, et donc qui crée le couple moteur. C’est pour cette raison que nous utilisons un ESC (Basic ESC BlueRobotics 2-6S/ 7-26V).

Un ESC (Electronic Speed Controller) est un contrôleur spécifique aux moteurs brushless puisqu’il envoie un signal plus ou moins fort au moteur et répond donc au principe présenté précédemment.

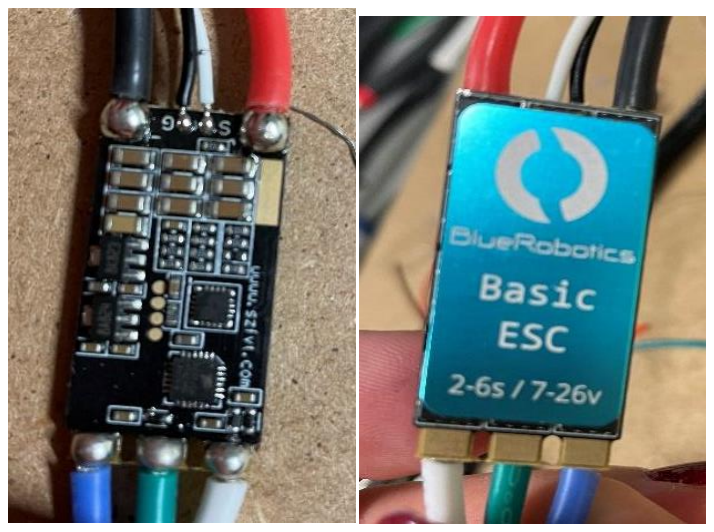
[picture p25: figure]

Figure 29: Photos de l’ESC utilisé

### 4.1.1 Tests du couple moteur

Le système d’attache du moteur consiste en un coude d’acier auquel nous avons vissé le moteur et ajouté un serre-câble maintenant le moteur afin qu’il ne se déplace pas avec la puissance et la force qu’il va appliquer. Nous avons ensuite modélisé et créé, à la CNC, une barre de 30cm disposant de 5 trous, permettant l’attache de poids, à laquelle nous avons fixé un marteau en guise de poids.

Ce système nous a permis de vérifier si le moteur était capable de soulever le marteau sans difficulté ou non. Le test étant concluant, le moteur a tourné correctement. Nous avons donc ensuite modélisé et imprimé en 3D une pièce supplémentaire permettant d’ajouter un encodeur sur le moteur, afin de nous donner la position angulaire du moteur.


Figure 30: Modélisation des attaches du moteur

Figure 31: Attaches du moteur en place

L’ajout de l’encodeur est nécessaire pour vérifier le maintien de la position donnée malgré la présence du poids. Pour calculer le couple déployé par le moteur, nous avons observé l’évolution du courant traversant le moteur.

I (A) | Poids (kg) | Distance poids – arbre moteur (cm)
1.6 | 2 | 15.5
Figure 32: | Photo et conditions des tests

Calcul du couple : C = d ∗ F = d ∗ mg = 15.5 ∗ 10⁻²

| ∗ 2 ∗ 10³ ∗ 9.81 = 3.04 Nm

D’après les tests précédents, pour soulever un marteau de 2kg, le moteur nécessite 1.6A sur les 3 possibles. Il déploie ainsi un couple de 3.04Nm, ou une force de 19.62N. Selon certaines études (Cf partie 6.3), un nageur déploie une force de poussée d’environ 5N dans une piscine. Due à la présence de courants et de vagues, nous pouvons aisément affirmer qu’il devra déployer une plus grande force. Néanmoins, avec un courant de 1.6A, nous déployons un couple qui semble suffisant pour nager en sachant que nous pouvons faire plus avec ce même moteur. Afin de confirmer ces hypothèses, nous avons procédé à une nouvelle batterie de tests, cette fois-ci avec un poids de 2.5kg.


Figure 33: Tests avec 2.5kg

### 4.2 Recherche de composants

Après ces différents tests, nous avons fait une recherche de composants pour la création du robot à l’échelle 1:1, notamment sur les moteurs à utiliser. Nous avons réussi à retrouver le même moteur ainsi que le réducteur sur lesquels nous avons fait des tests. Nous avons également cherché des joints spi et des coupleurs d’axes. En effet, ils nous sont nécessaire afin de faire sortir l’axe moteur des tubes étanches. Notre arbre moteur ayant un diamètre de 12mm, nous avons réfléchi à un moyen de le faire rentrer dans le coupleur d’axe qui a un diamètre de maximum 8mm. N’ayant pas reçu les coupleurs avant la fin des séances de projets, nous n’avons pas pu tester le réducteur.

## 5 SURETE DE FONCTIONNEMENT

Problèmes possibles | Causes possibles | Résolutions à envisager
Perte du suivi de bouée (or du champ de vision) | Ensoleillement provoque des reflets endommageant l’algorithme de détection | Si courte durée alors garde le cap

Une vague submerge la caméra

Caméra HS ou s’est décrochée Si persiste alors il faut tout stopper Carte 1 HS

Moteur(s) HS | Force appliquée pour le mouvement trop importante | Changement du moteur, et ré-étude du choix moteur
| Défaillance | Si un des moteurs des jambes est HS → continuation de la mission seulement avec les bras (arrêt de la jambe opérationnelle)

Si un des moteurs des bras est HS → arrêt total du robot.

Contact avec l’eau (pour les non-étanches)

Changement de certaines parties du robot si manque d'étanchéité

Casse d’une articulation

Résistance trop faible des
matériaux | Nouvelle modélisation de la pièce suivant
Force trop forte appliquée sur | la cause de la casse (épaisseur, taille…)
l’eau
Choc avec divers objets (planche
de surf, bouée, cailloux…) | Refabrication de l’articulation (avec un
| matériau différent suivant la cause de la
casse) Dégradation due à l’eau salée (rouille, détérioration)
Carte HS | Court-circuit (prise d’eau) | Changer la carte
| Batterie HS | Refaire l'étanchéité du tube
| Détachée dans le tube et a reçue des chocs | Changer l’attache de la carte par un modèle plus solide
| Surchauffe | Modifier la programmation ou la disposition dans le tube
Batteries tête/corps HS | Batterie épuisée | Changer la batterie (redimensionnement si nécessaire)
| Contact avec l’eau | Refaire/vérifier l'étanchéité

Déviation de trajectoire

Un bras plus rapide | Réadaptation des moteurs du point de vue
| du code (ne pas mettre exactement les
Vague | mêmes vitesses)

Mauvais calcul de trajectoire

| Ajout de la prise en compte d’une erreur
| dans le code

Mauvaise interprétation des données (erreur vue comme
trajectoire, moteur pas précis,
mauvaise transmission et modifie
la valeur…)
Défaillance des moteurs d’un bras | Vérification des valeurs reçues avec des encodeurs
Coule ou flotte | Répartition poids/volume | Mesures/calculs pour meilleur répartition
| Salinité de l’environnement ou densité | Mesures de l’environnement pour adaptation

## 6 ANNEXE

### 6.1 Modélisation

### 6.2 Programmation

### 6.3 Implémentation

Etude nageur de crawl :
https://gregoirerichard99.wixsite.com/performancesnatation/blank-kr699

Coupleur d’axes :
https://www.gotronic.fr/art-coupleur-d-axes-8-8-mm-cl1m88-20808.htm

Joint spi :
https://www.123roulement.com/joints-OAS-8X14X5-NBR

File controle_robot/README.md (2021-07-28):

# Robot nageur

## Electronique 

Le choix de l'électronique de ce robot n'est pas encore faite. En effet, nous sommes actuellement capable de réaliser le mouvement et de commander le robot via la BBB cependant elle ne permet par de réaliser une boucle fermée. La difficulté de ce robot se retrouve dans son mouvement. En effet, réaliser une nage crawlée nécessite une adaptation de la force appliquée suivant l’environnement (eau ou aire). La force appliquée sous l’eau est bien plus importante qu’en dehors si l’on souhaite obtenir une trajectoire et un mouvement constant. Pour cela il faut donc utiliser un système de commande en boucle fermée, et pour cela nous avons donc du étudier les cartes trinamic qui elles réalisent quasi-automatiquement cette boucle fermée.

Afin de réaliser notre robot il nous a fallut étudier comment le contrôler et comment le commander.
Ainsi nous avons donc approximer notre système à ce schéma bloc :

schéma bloc

Ce type de système en boucle fermée nous permettra, grâce aux mesures effectuées par nos codeurs et IMU d’ajuster la commande envoyée à notre robot pour lui permettre d’effectuer un mouvement plus fluide, plus juste et de vérifier les positions au cours du temps. La commande envisagée est donc appelée « commande hybride couple-position ».

## Controle des moteurs du robot nageur

Deux solutions ont été abordées: 
  - Avec une BeagleBone Blue reliée aux moteurs par des ESC. Nous arrivons à contrôler les moteurs en boucle ouverte grâce aux encodeurs, et ainsi à reproduire le mouvement de crawl d'un bras. Nous avons également essayé le retour en boucle fermé
  - Avec une Trinamic, qui contrôle toute seule en boucle fermée avec davantage de précision

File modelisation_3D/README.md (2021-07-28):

# Modélisation 3D

Dans ce dossier-là, vous disposerez de l'ensemble des pièces créées pour l'épaule de notre robot.
Voici une modélisation correspondant au système étudié lors de notre stage :

modélisation bras

bras réel

## Choix de cette conception du bras

Cette conception du bras nous a été imposée par notre tuteur. Elle consiste à réaliser les rotations coudaire et du biceps à partir de la relation entre 2 moteurs de drones (AXI 2217/12 GOLD LINE). En effet, pour réaliser une rotation uniquement coudaire il suffit de n'activer qu'un des moteurs (dans ntore cas le moteur 1) et pour réaliser une rotation du biceps il nécessite d'ajouter l'effort réaliser par les 2 moteurs. Un ajout de réducteur ( système d'engrenage/roues dentées avec rapport de réduction 60:1) a été nécessaire pour obtenir une vitesse réelle de rotation du bras.

modélisation simplifiée du bras

Pour ce qui concerne l'épaule, le choix du moteur a été imposé également puisque nous l'avoir récupéré d'un autre projet. Vous pouvez retrouver l'étude de son couple et de ses caratérisque dans le document *Rapport_de projet_robotique* (https://github.com/Katell-Lag/robot_nageur/blob/main/modelisation_3D/Rapport_de%20projet_robotique.pdf) à la partie 4.1.1

## Résultats obtenus

Comme vous pouvez le constater l'inconvénient de cette conception du bras est sa répartition du poids du bras. En fait, 2 des moteurs du bras se trouve au niveau du coude, ainsi tout l'effort créé par les moteurs prend en compte le poids de l'ensemble d'entre eux, et la distance épaule-coude est bien trop grande pour réduire cet effort.
En plus de cela, étant donné que les rotations du coude et du biceps se réaliser après réduction des moteurs -réaliser par un système d'engrenage/roues dentées (réduction 60:1)-, le poids, les minimes imprécisions de mesures etc. ne permettent pas de réaliser le mouvement correctement. C'est-à-dire que certaines dents des roues dentées peuvent sauter ou riper, un accou important lors de la descente du bras se réalise etc.

Ce prototype malgré ses nombreux défauts, nous a été très utile, puisqu'il nous a permis de constater que la fixation de l'axe des roues dentées n'était pas suffisante et qu'un deuxième point d'attache est nécessaire. Que l'axe de raccord moteurs-biceps n'était pas assez long. Et qu'il faut rapprocher au plus les moteurs vers l'épaule.

##### Notez que la modélisation a été réalisée sous OnShape un logiciel de conception assistée par ordinateur (CAO) disponible en ligne.
https://www.onshape.com/en/

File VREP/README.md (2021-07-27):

# SIMULATION V-REP

### SIMULATION DE L'ARCHITECTURE

L’architecture du robot créé sous V-REP est celle du vrai robot : un buste, deux bras, deux jambes. 

Les articulations sont modélisées par des joints cylindriques et les parties mécaniques par des cylindres. Le buste est fixe et modélisé par un pavé droit. C’est la première pièce dans l’arbre des dépendances.

### COMMANDE EN POSITION  

Les 8 moteurs (3 par bras et 2 pour les jambes) doivent être commandés en position. Nous avons récupéré le tableau de valeurs de l’ancien groupe, qui correspond aux angles que doivent atteindre chaque pivot à chaque instant. Ce sont donc les différents objectifs que les objets doivent atteindre. 

Le programme a été fait en Lua. Avec la fonction sim.setJointTargetPosition de V-REP et en adaptant les unités et les repères, les 6 moteurs ont pu être commandés en position grâce au tableau de valeurs (voir le child script associé).

La commande se fait de cette manière: lorsque les objets ont atteint l'orientation objectif qui correspond à une valeur du tableau, l'objectif change et devient égal à la prochaine valeur du tableau.

La synchronisation des deux bras se fait avec un décalage d'indices: les deux bras parcourent de manière décalée le même tableau de valeurs.

Nous avons également voulu simuler le milieu aqueux sous V-REP en ajoutant des frottements avec la fonction "*sim.addForceAndTorque*" lorsque le bras était censé être dans l’eau. Nous avons également testé différents paramètres comme la densité des pièces, leur poids etc. La réaction du bras sous V-REP s'est trouvée être imprévisible et peu réaliste, ainsi nous avons laissé cette piste de côté.

###### Notes : il se peut que les simulations s'exécutent mal, à cause du temps de calcul et simulation trop lent.

### Coder sous V-REP

Nos codes se situent au niveau des "primitives" (ou objets) de V-REP. Pour les voir, double-cliquer sur l'icône à côté des noms des objets dans l'arbre des dépendances.

Pour coder sous V-REP directement en Lua, il faut se placer sur la "primitive" à commander, puis cliquer sur Add -> Associated Child Script -> Non Threaded.

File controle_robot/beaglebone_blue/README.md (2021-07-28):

# CONTROLE DES TROIS MOTEURS EN BOUCLE OUVERTE AVEC LA BEAGLEBONE BLUE

La carte BeagleBone Blue (BBBlue) est une carte de développement open source fonctionnant sous linux.
Disposant de divers modules et interfaces (UART,SPI, IMU, Bluetooth) nécessaires pour notre utilisation et de connecteurs moteurs, cette carte est idéale pour la commande de nos moteurs.

L’un des nombreux avantages de cette carte est que l’on peut accéder à son contenu (codes, exécutables…) via WIFI. On parle de liaison SSH. Cette liaison permet d’ouvrir une session interactive entre une machine distante et le client. Soit nous et la BBBlue (son environnement linux). Ainsi il nous est donc possible de modifier une commande sans démonter le système électronique.

La BBBlue possède dès son utilisation tout une architecture linux. Elle possède également divers exemples de code suivant les modules utilisés, des configurations de GPIO ou autre. C’est donc avec l’appui de ces divers exemples que nous avons implémenté un code permettant de commander les 3 moteurs. 

## Notre utilisation de la BBBlue

Ainsi disposant de 8 connecteurs moteurs et 4 pour les encodeurs, nous avons choisi de commander 3 moteurs Brushless contrôler par 2 encodeurs avec une unique BBBlue.
Il sera donc nécessaire de disposer de 2 BBBlue pour commander l’ensemble des moteurs.
Ce dossier contient donc le code et les makefile nécessaires pour faire fonctionner les trois moteurs (moteur épaule et les 2 moteurs du bras) en boucle ouverte, à l'aide des encodeurs du moteur épaule (encodeur 4) et du moteur 1 (encodeur 1). Nous appelons moteur 1 le moteur relié au channel 1-c'est le moteur dont l'axe est le plus bas-.
A l'exécution du code, les trois moteurs simulent la trajectoire de crowl d'un bras. 

###### NOTE: Nous ne l'avons fait fonctionner que sur table, car on rencontre des soucis de jeux entre les dents des engrenages.

## Architecture 
Ainsi l’architecture envisagée pour la structure finale du système serait la suivante :

architecture générale

c : type de connexion
p : nombre de ports/fils envisagés

## Environnement :

L'image de la BeagleBone est debian et la librairie utilisée est librobotcontrol.
La Beaglebone sur laquelle nous avons réalisé les tests est la BeagleBone-BB35. Pour accéder à son contenu, il faut se connecter en WIFI à celle-ci puis en SSH(Putty, WinSCP ...) avec les parmètres suivant : 
###### ip: 192.168.8.1
###### utilisateur: debian
###### mdp: temppwd

## Branchements : 

*voir schéma ARCHI_BBLUE.png*
architecture BBB

Remarque: les moteurs tournent sous du 12V, 3A (max)

## Exécution de code :

Vous trouverez dans le dossier *librobotcontrol-1.0.4/examples* plusieurs codes réalisant diverses commandes.  
Le code fonctionnel est: librobotcontrol-1.0.4/examples/codes_tests/rc_moteurs_synchros.c
Pour l'exécuter il faut se placer dans le dossier *librobotcontrol-1.0.4/examples*, réaliser un "*make*" afin de créer l'exécutable du fichier de commande rc_moteurs_synchros.c.
Ainsi le fichier exécutable est créé dans le dossier codes_tests et pour lancer l'exécution la commande à entrer est la suivante :
##### rc_moteurs_synchros -c 3 -a -250000 -f 400 -s 1.0 -m 1400,1600

### Commande

Le -c 3 correspond au channel du moteur épaule. Il faut donc bien le brancher sur ce channel. Le -m 1400,1600 correspond à la plage du pwm. Si on veut faire tourner le moteur plus ou moins vite il faut agrandir ou réduire cette plage centrée en 1500. Le -s correspond au switch mode (celui que l'on utilise). Les autres paramètres sont des paramètres par défault.

### Explications du code

Le contrôle se fait grâce aux valeurs des encodeurs (voir commentaires du code dans le switch mode).
La première rotation du mouvement se fait avec les deux moteurs tournant dans le sens opposé, et le second mouvement uniquement avec le moteur 1.
Il faut faire attention au sens de comptage des encodeurs qui peut être négatif (voir code).

CONTROLE EN BOUCLE FERMEE

Le code associé à la boucle fermée est librobotcontrol-1.0.4/examples/src/rc_moteurs_tour_entier_fonctionne.c
Il s'agit d'un contrôle en vitesse. La variable "val" utilisée dans le SWEEP Mode est la valeur qui régule l'intervalle PWM de façon à avoir des différences de valeurs d'encodeur constantes. En effet, l'erreur correspond à ((valeur_actuelle_encodeur - valeur_ancienne_encodeur) - (valeur_de_reference)).

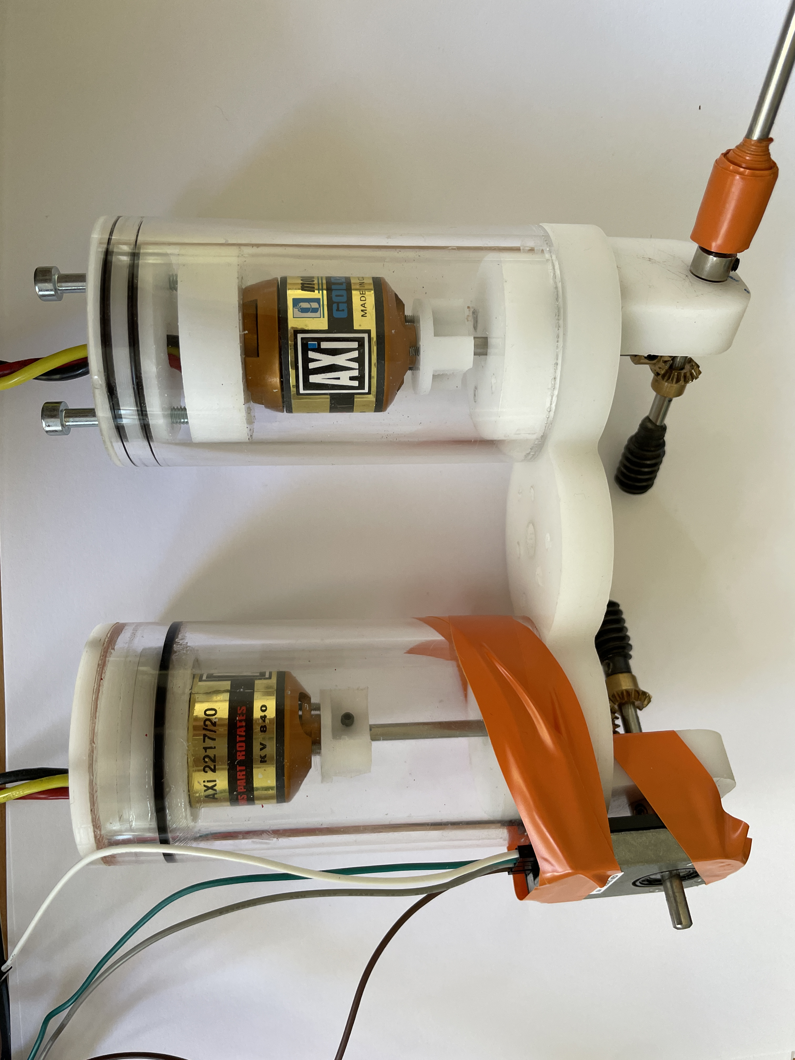
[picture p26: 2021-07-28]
modelisation_3D/Deux_moteurs.JPG

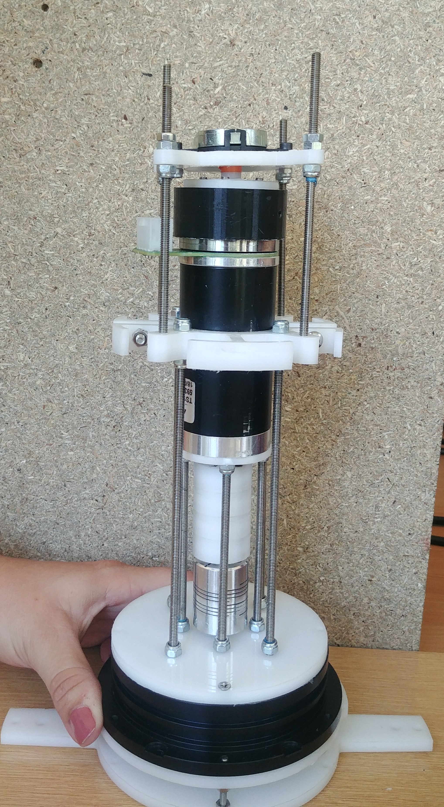
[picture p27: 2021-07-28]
modelisation_3D/epaule_finie.jpg

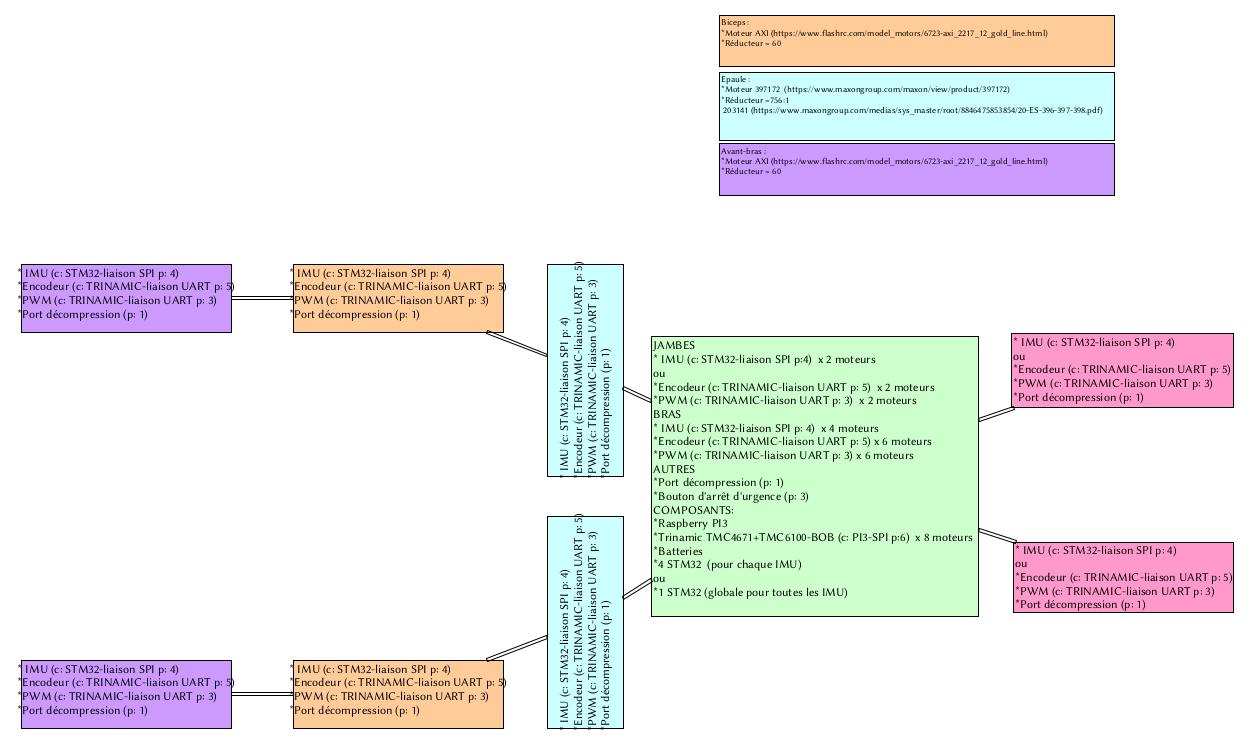
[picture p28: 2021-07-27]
controle_robot/Trinamic/TMC4671+TMC6100-BOB/archi_generale_TRINAMIC.jpg

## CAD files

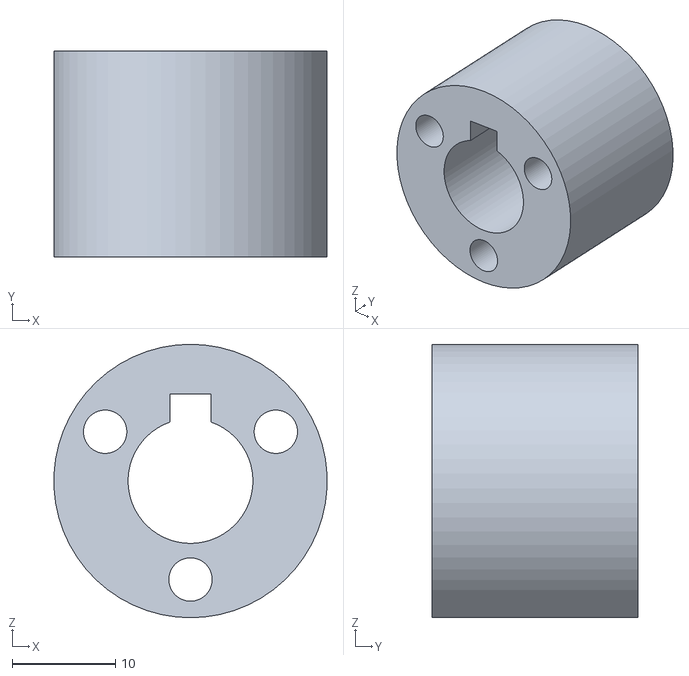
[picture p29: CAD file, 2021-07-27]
modelisation_3D/Part4.stl
26.5 x 20.0 x 26.5

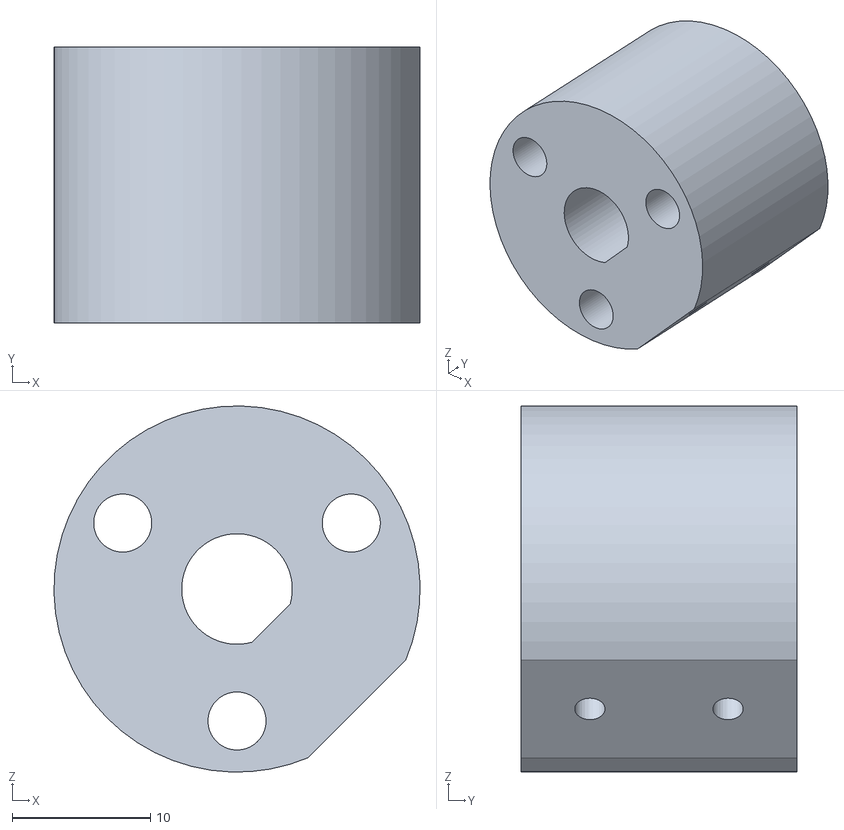
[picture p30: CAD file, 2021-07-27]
modelisation_3D/Part5.stl
26.5 x 20.0 x 26.5

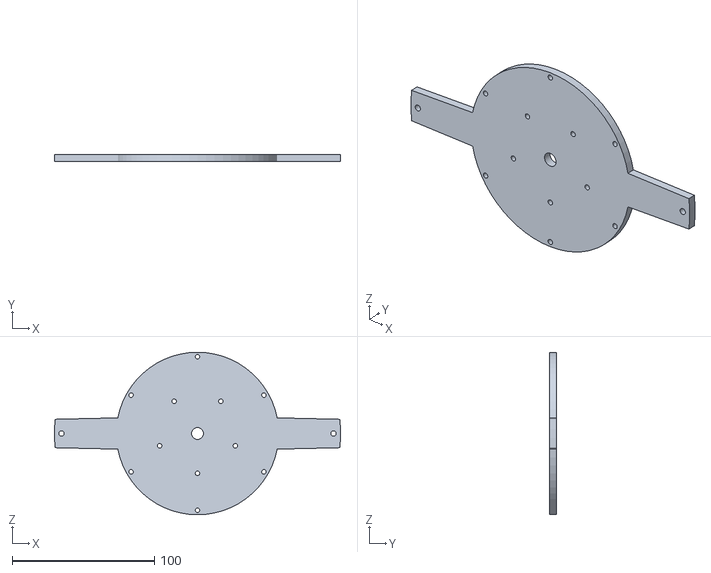
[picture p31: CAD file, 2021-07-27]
modelisation_3D/Part1.stl
201.2 x 5.00 x 114.3

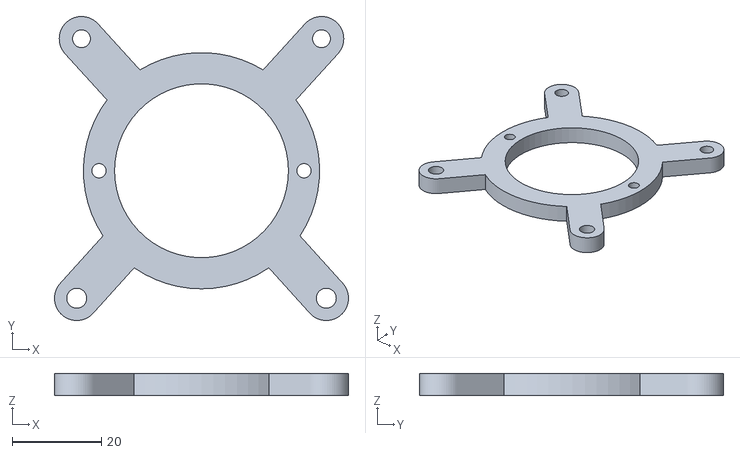
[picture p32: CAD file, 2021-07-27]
modelisation_3D/Part8.stl
66.0 x 68.2 x 5.00

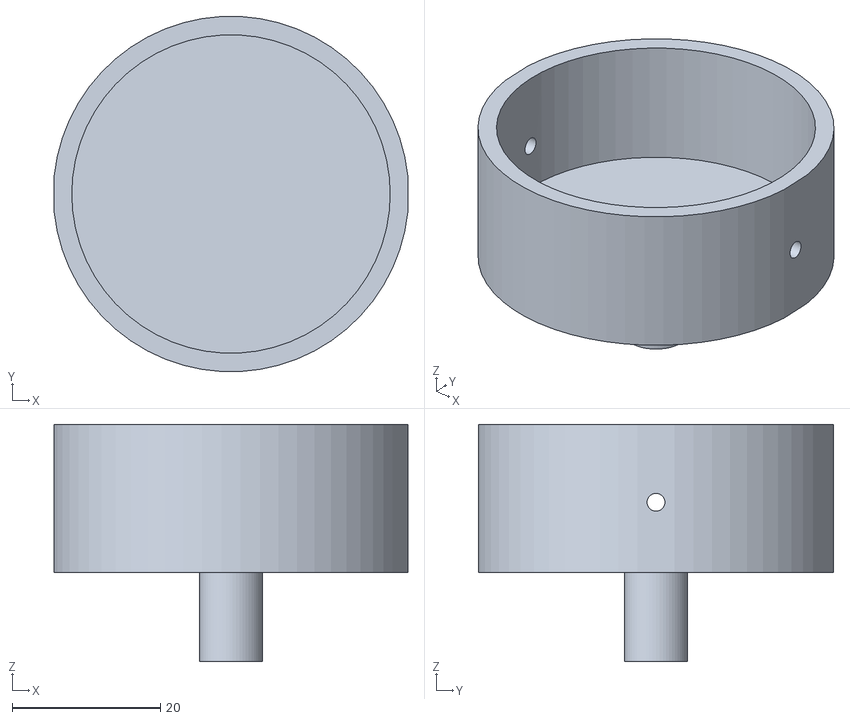
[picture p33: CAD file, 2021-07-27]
modelisation_3D/Part7.stl
47.7 x 47.9 x 32.0

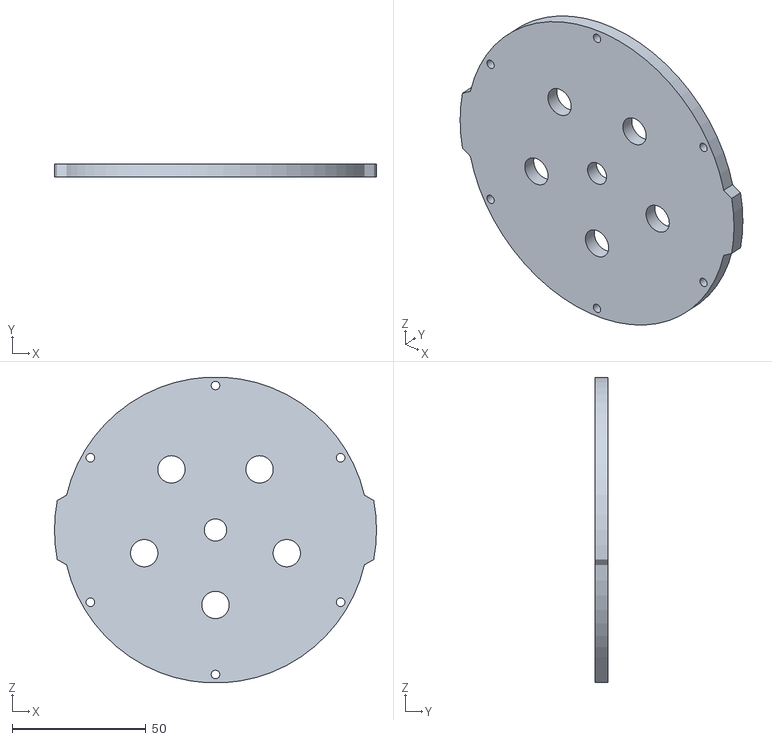
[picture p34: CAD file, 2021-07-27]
modelisation_3D/Part2.stl
120.3 x 5.00 x 114.1

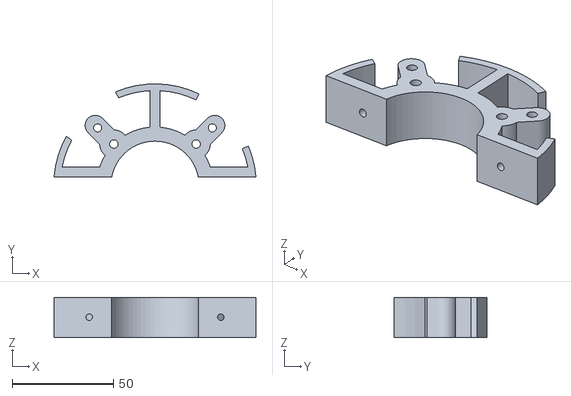
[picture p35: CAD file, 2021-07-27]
modelisation_3D/Part6.stl
99.8 x 46.0 x 20.0

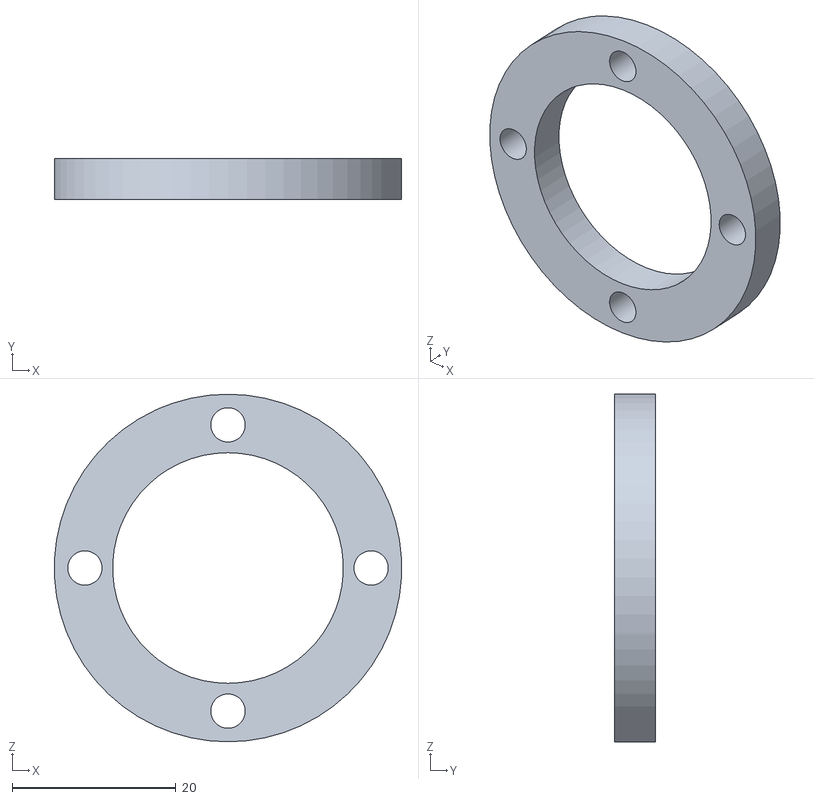
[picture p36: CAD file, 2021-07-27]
modelisation_3D/Part9.stl
42.4 x 5.00 x 42.5

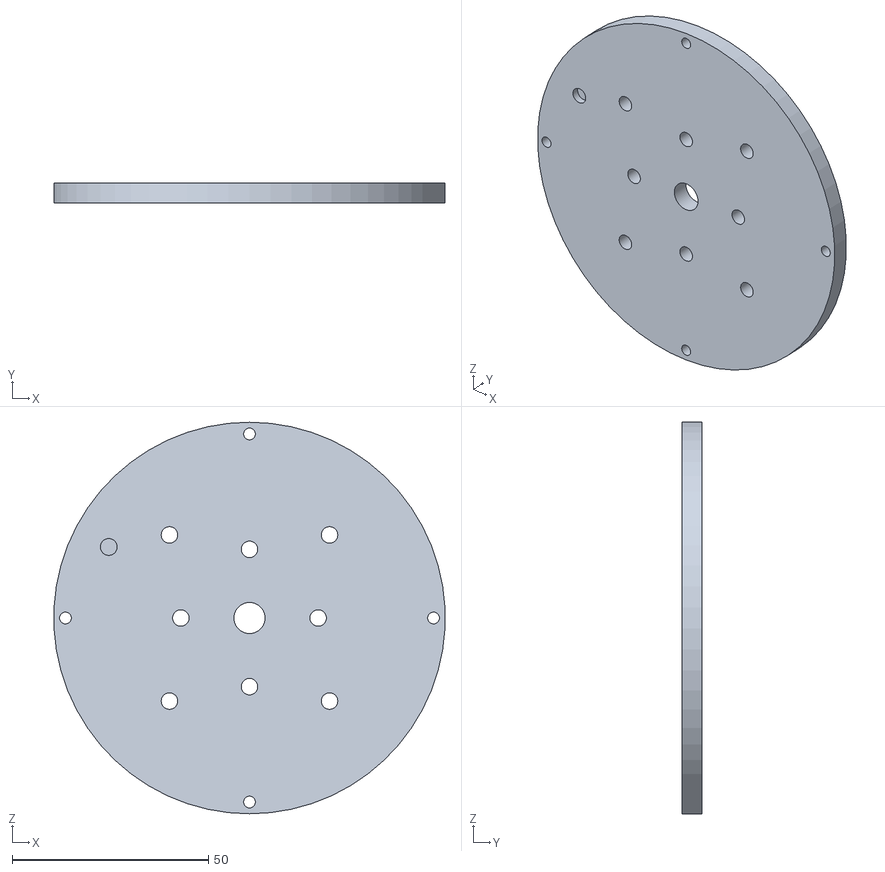
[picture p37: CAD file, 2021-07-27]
modelisation_3D/Part3.stl
99.7 x 5.00 x 99.8

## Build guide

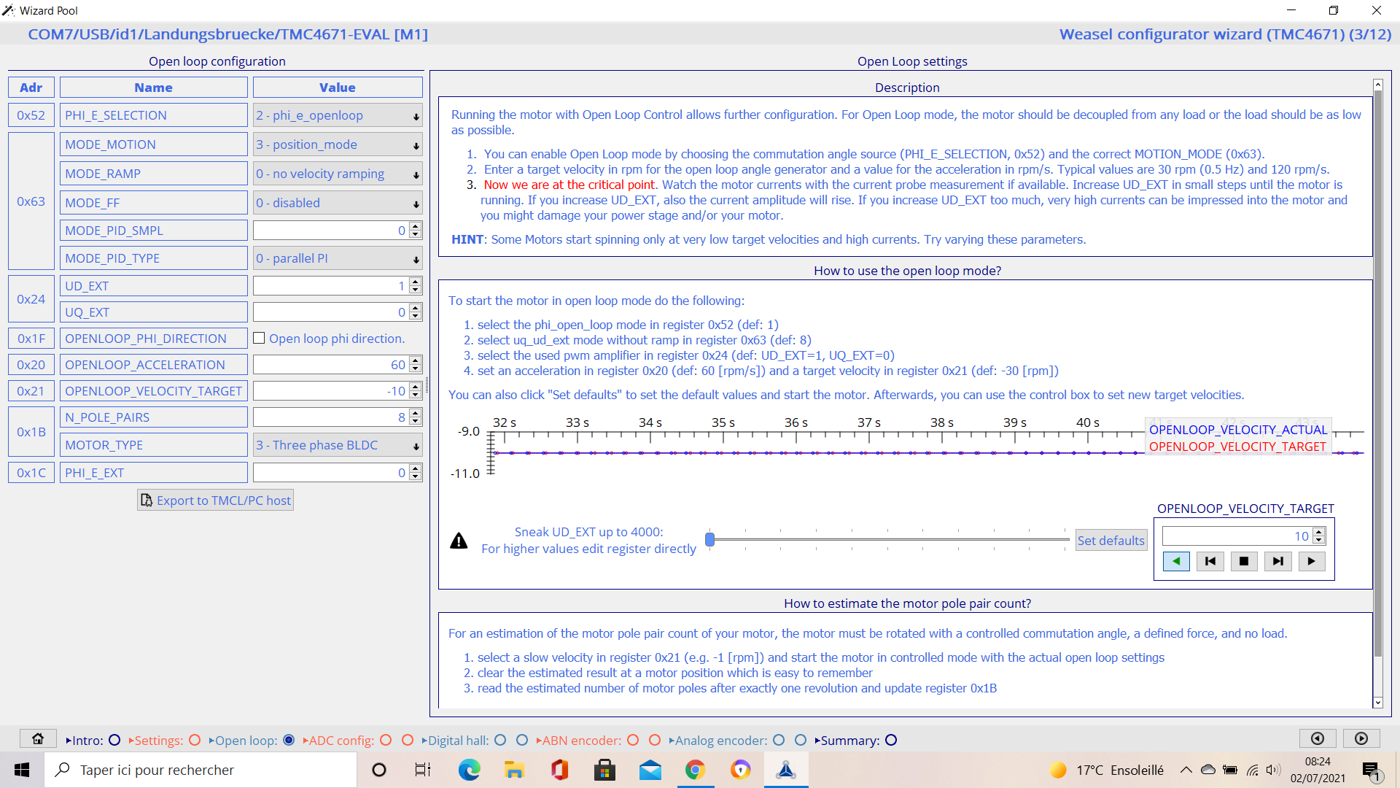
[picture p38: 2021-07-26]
controle_robot/Trinamic/TMC6100-EVAL-KIT/Setup/Capture2.PNG

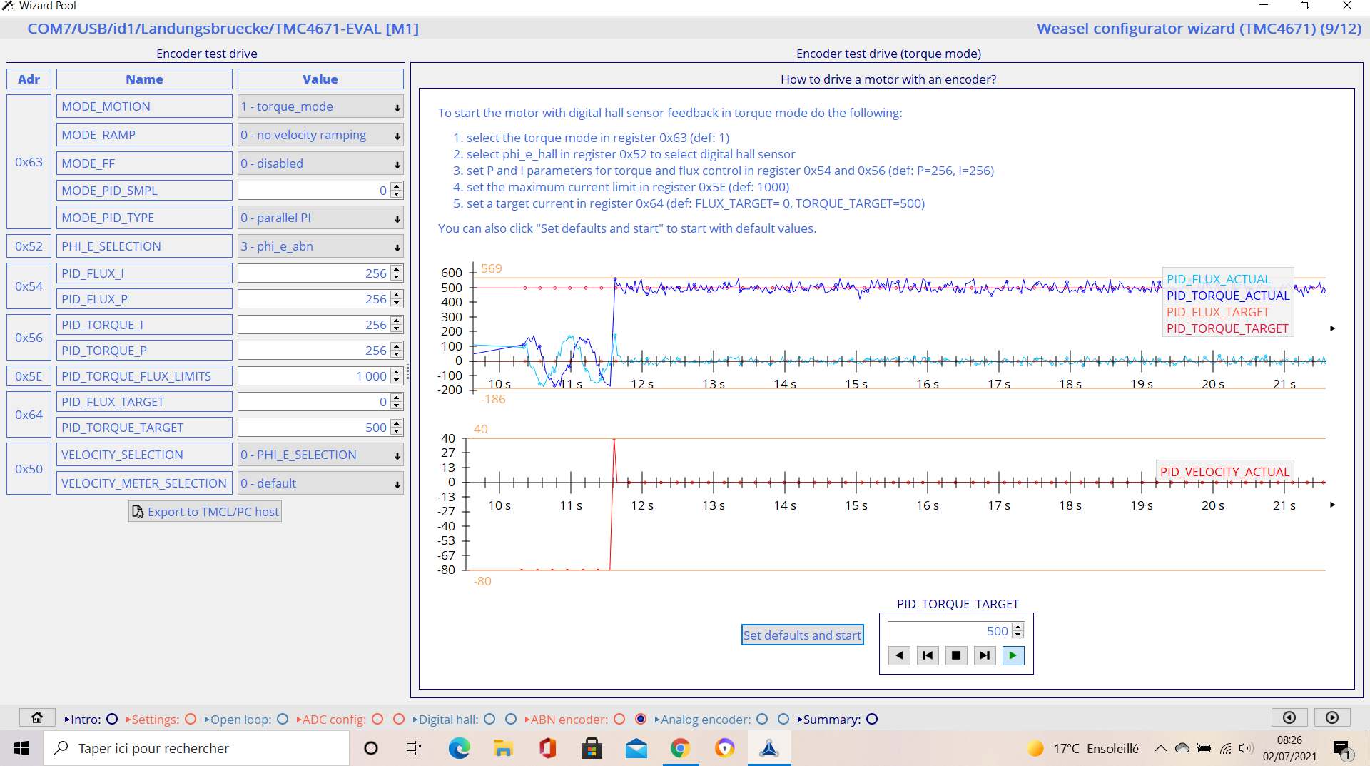
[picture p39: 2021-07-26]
controle_robot/Trinamic/TMC6100-EVAL-KIT/Setup/Capture4.PNG

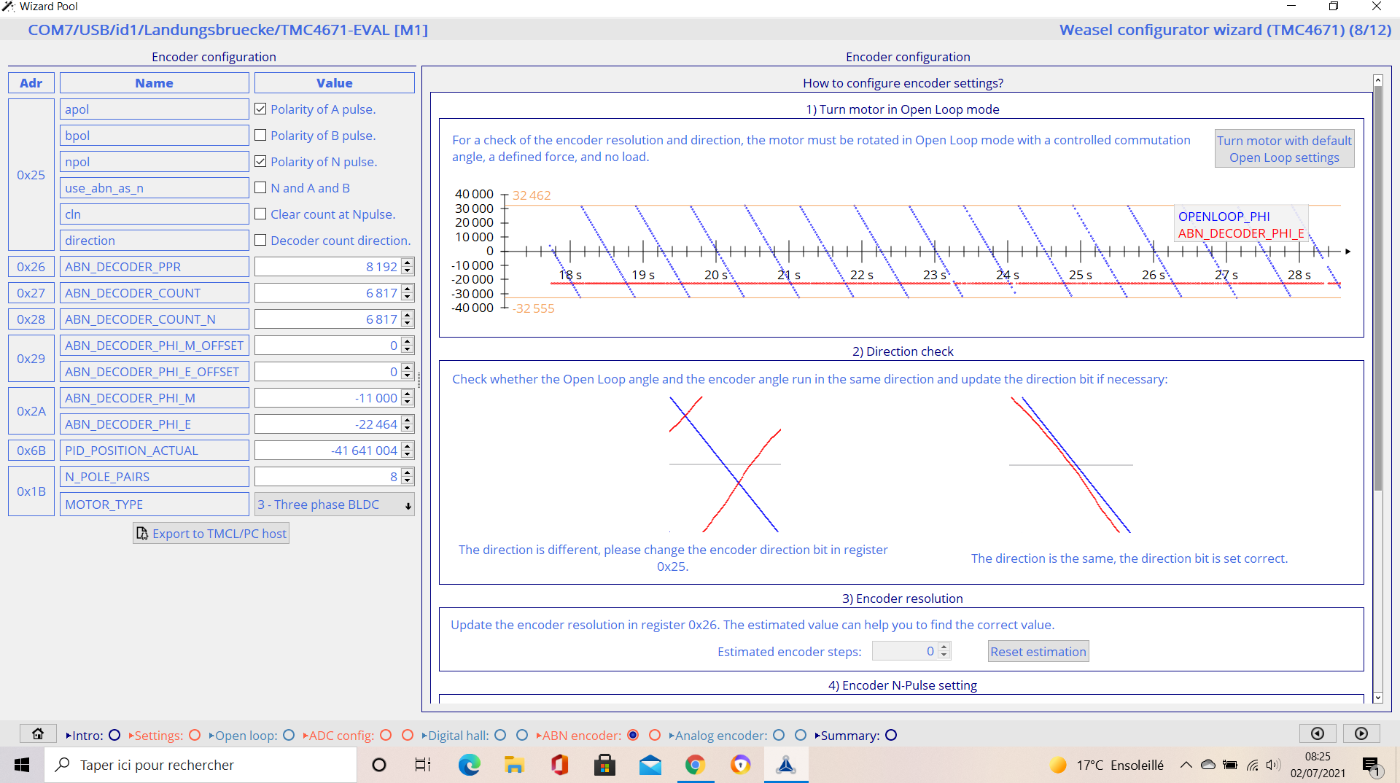
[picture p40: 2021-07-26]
controle_robot/Trinamic/TMC6100-EVAL-KIT/Setup/Capture3.PNG

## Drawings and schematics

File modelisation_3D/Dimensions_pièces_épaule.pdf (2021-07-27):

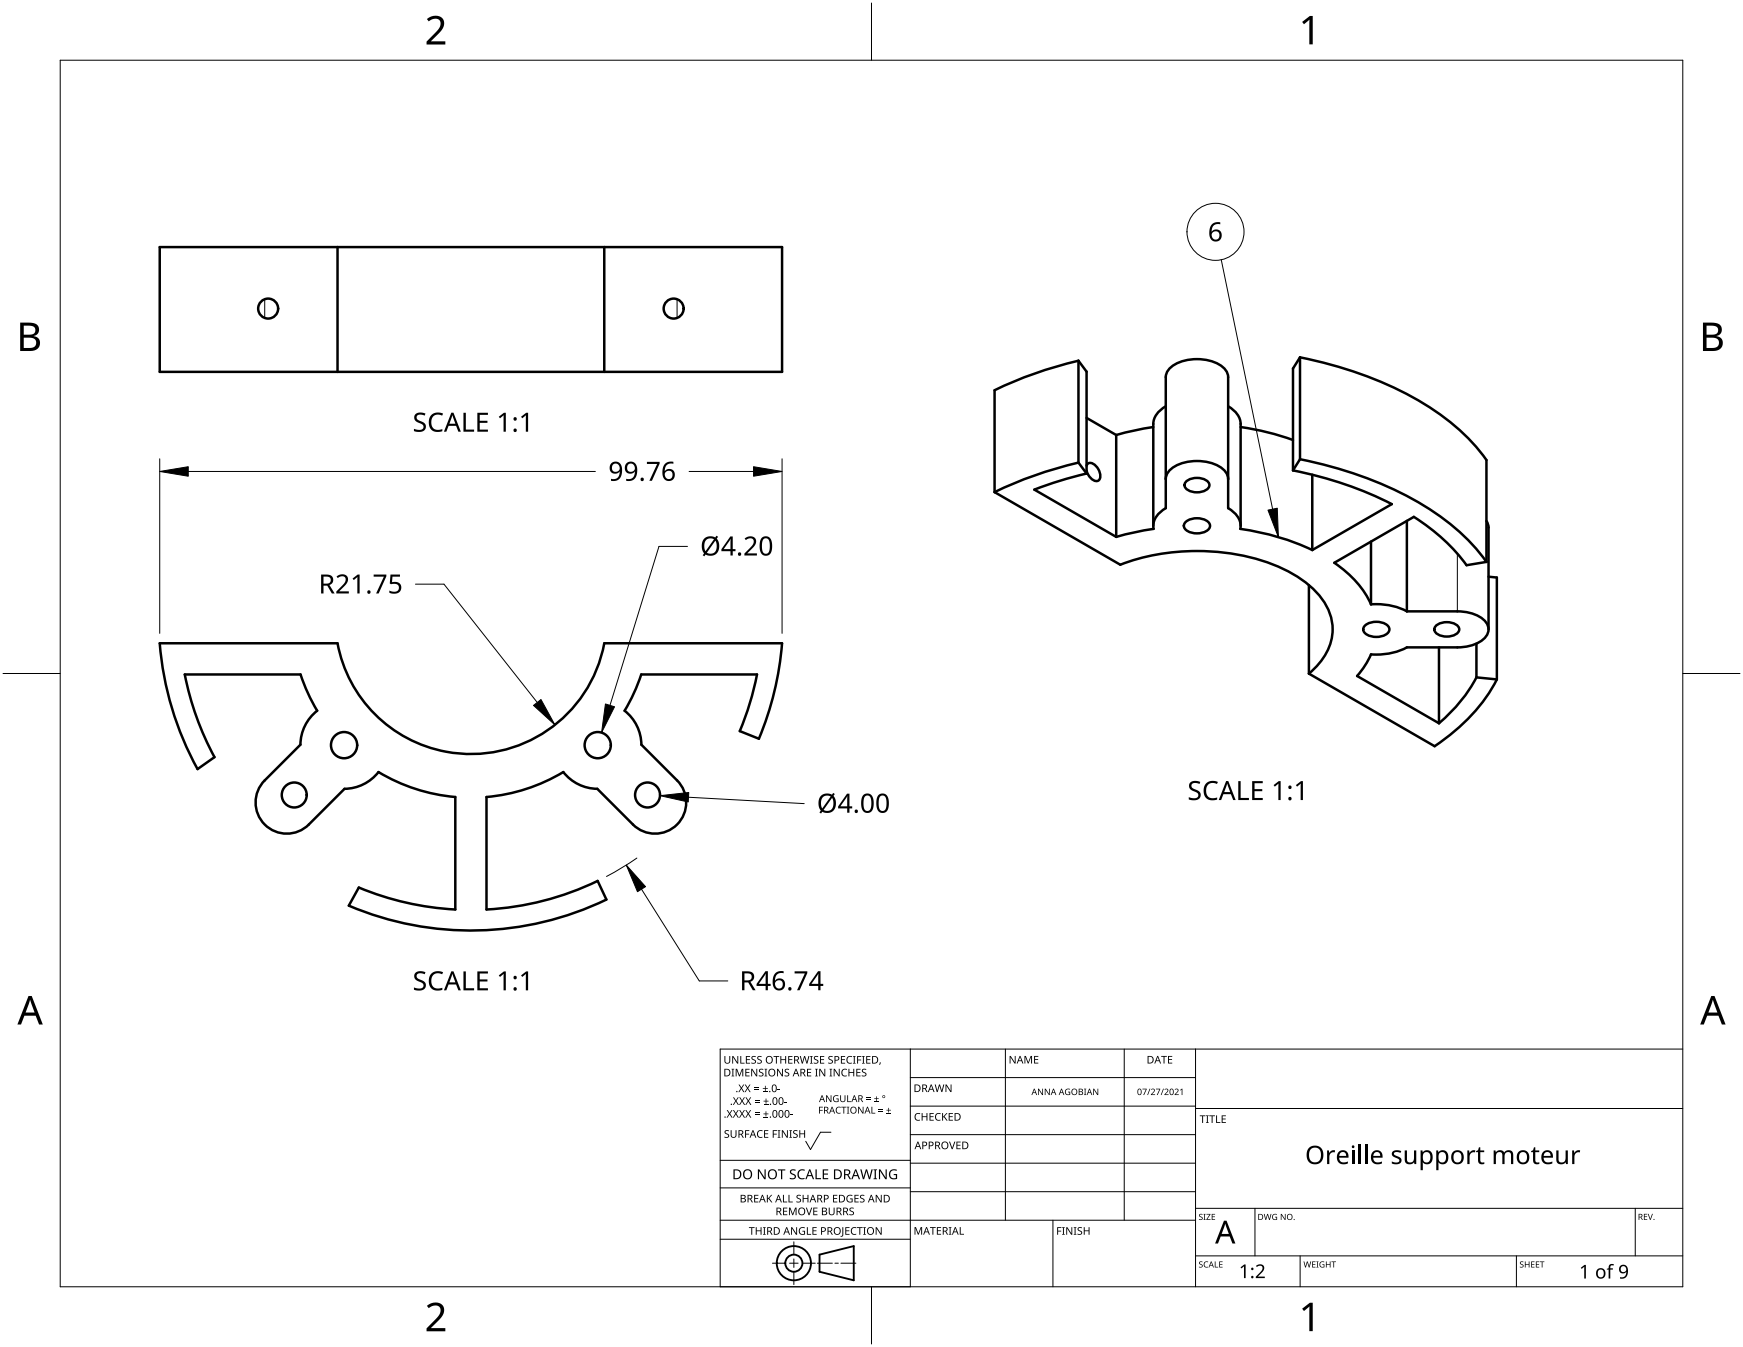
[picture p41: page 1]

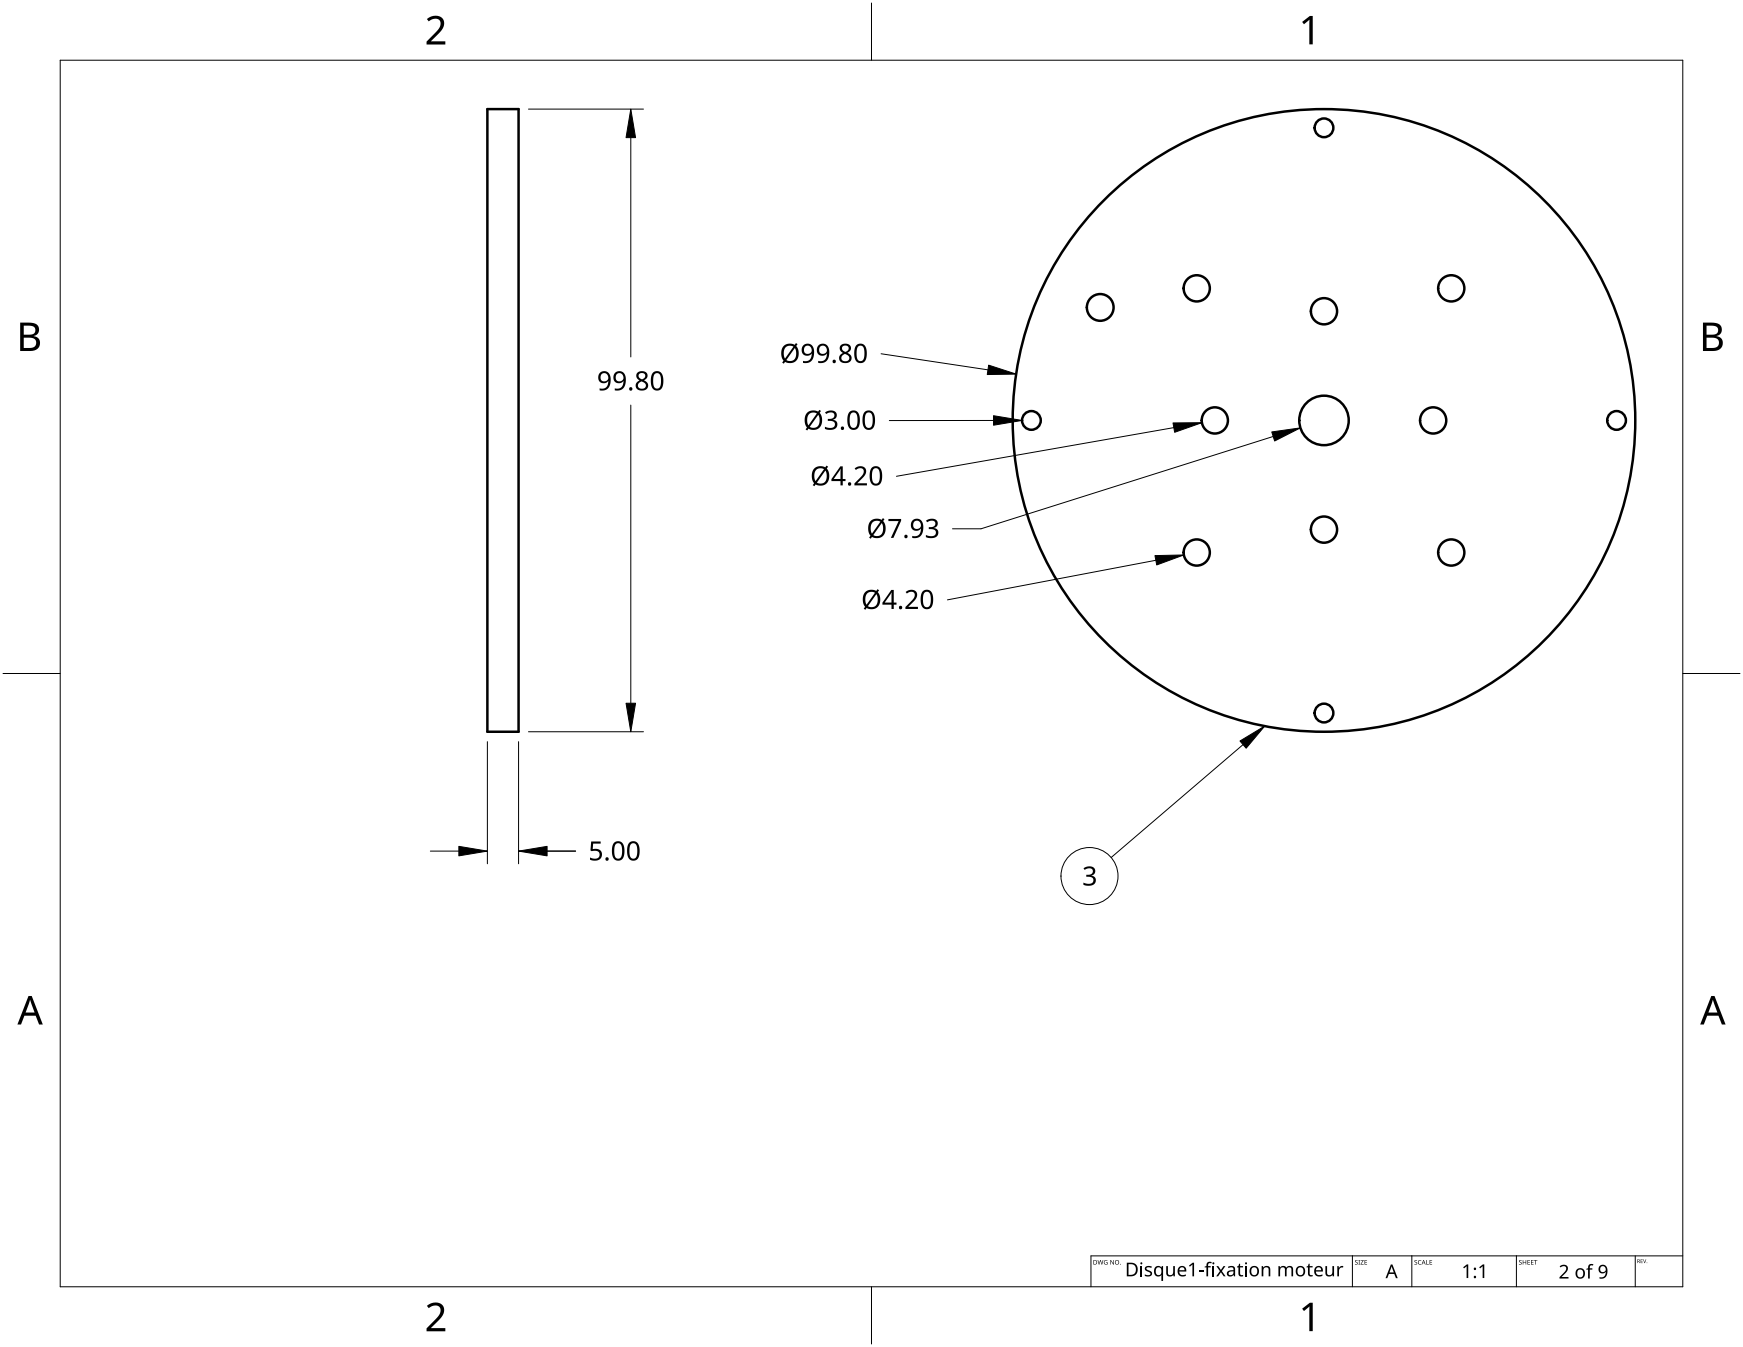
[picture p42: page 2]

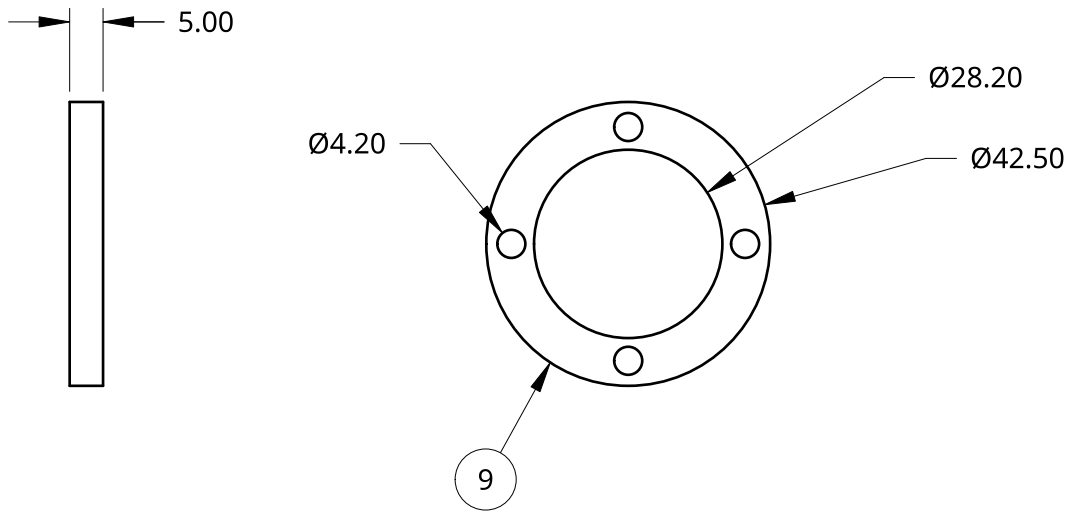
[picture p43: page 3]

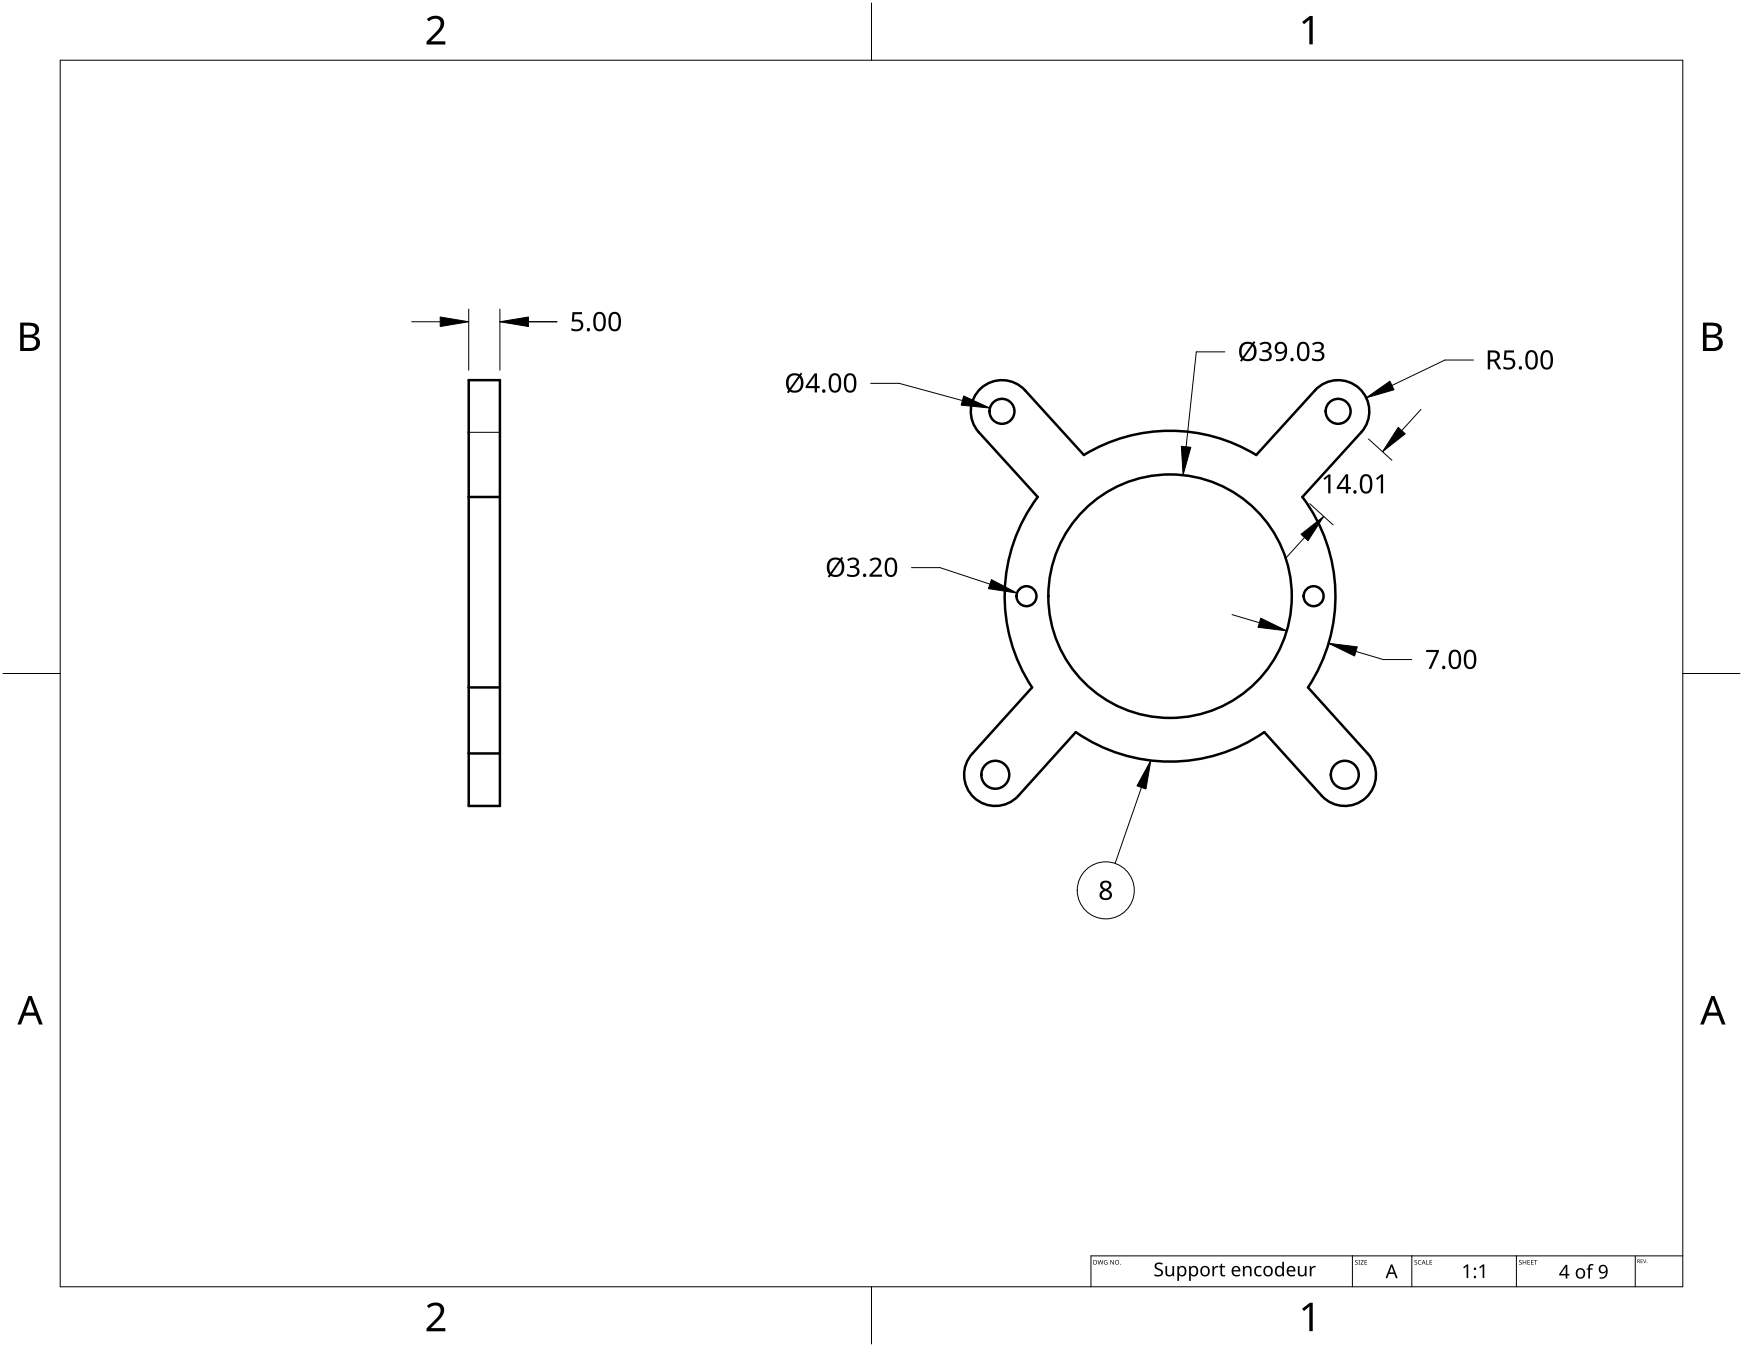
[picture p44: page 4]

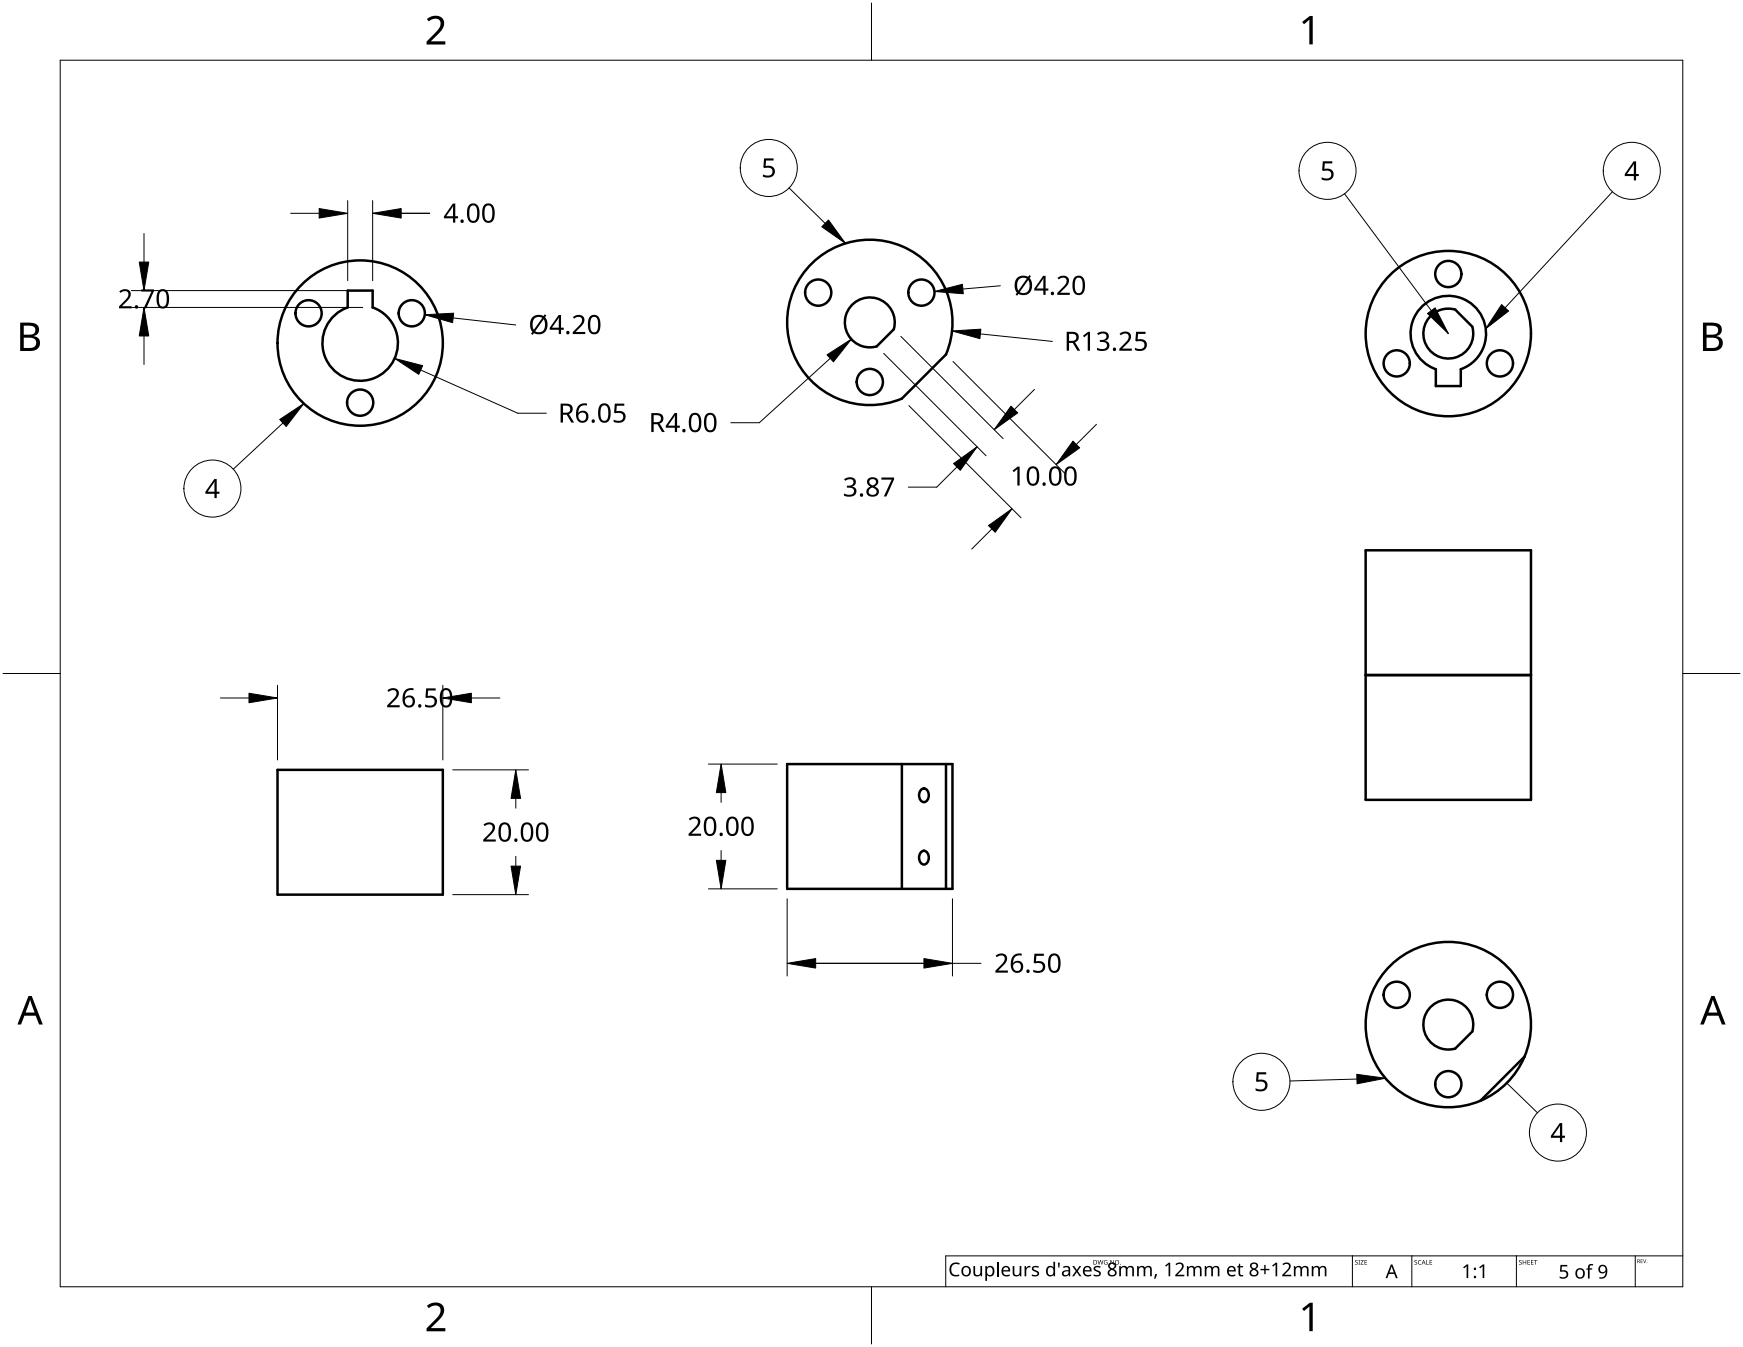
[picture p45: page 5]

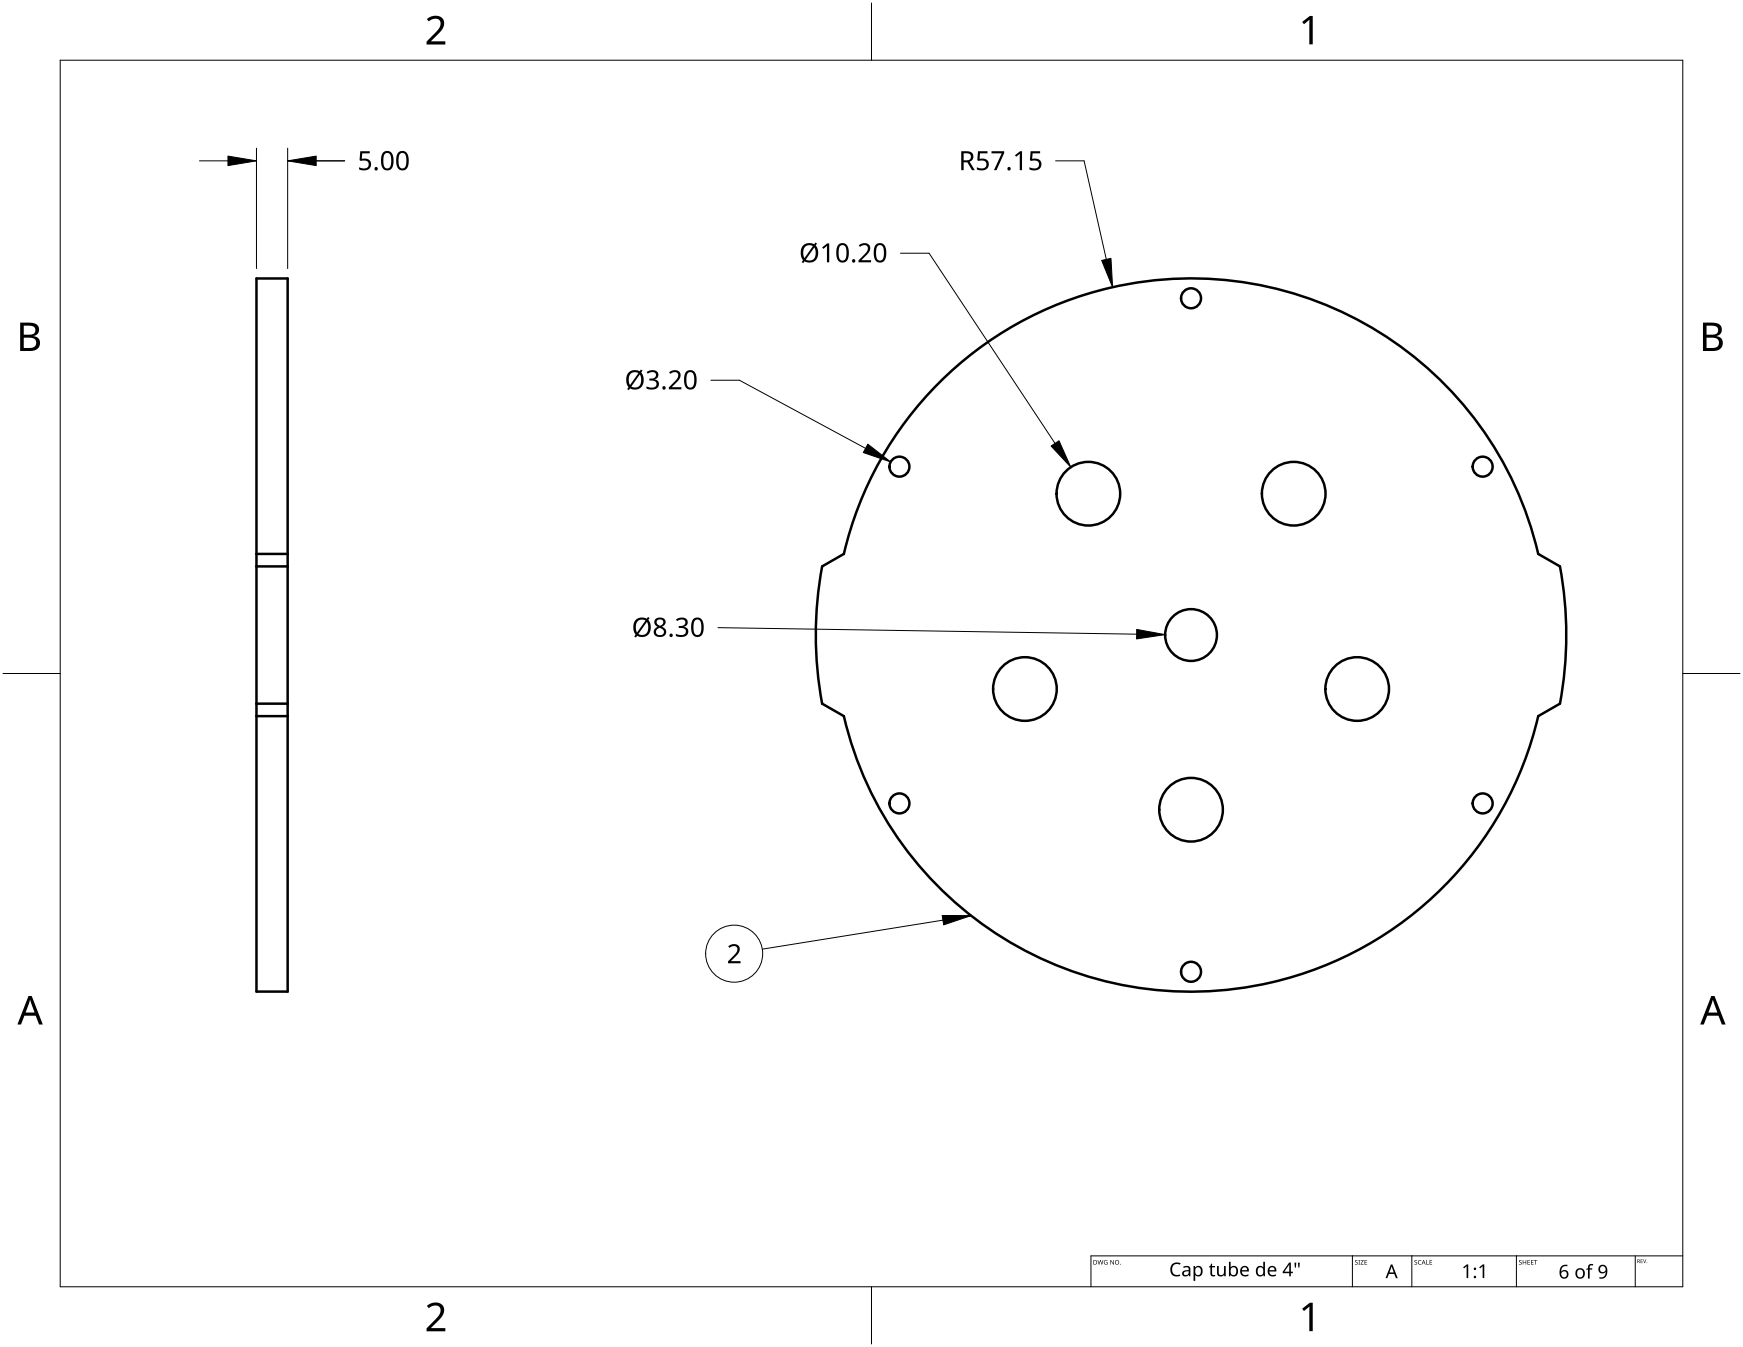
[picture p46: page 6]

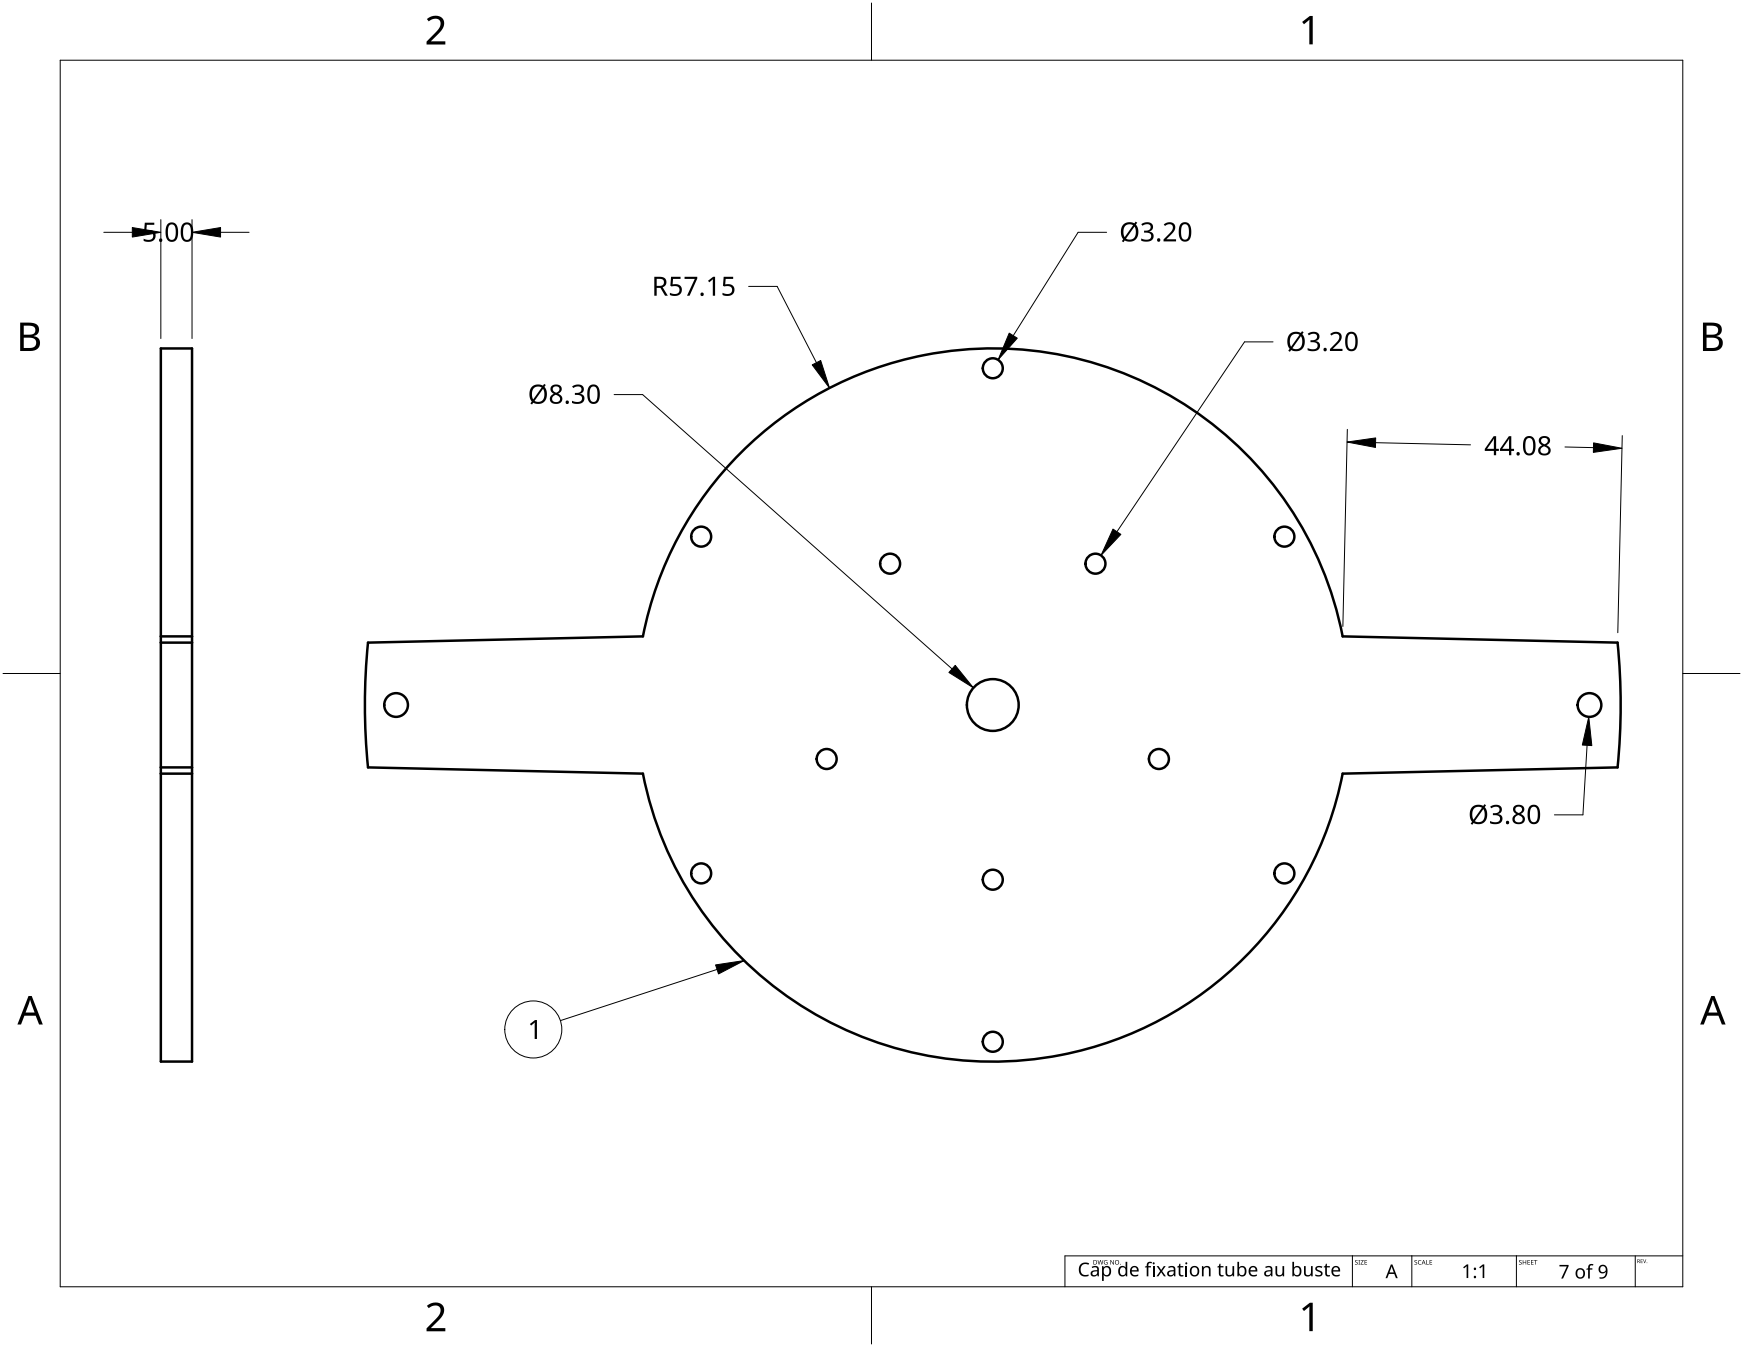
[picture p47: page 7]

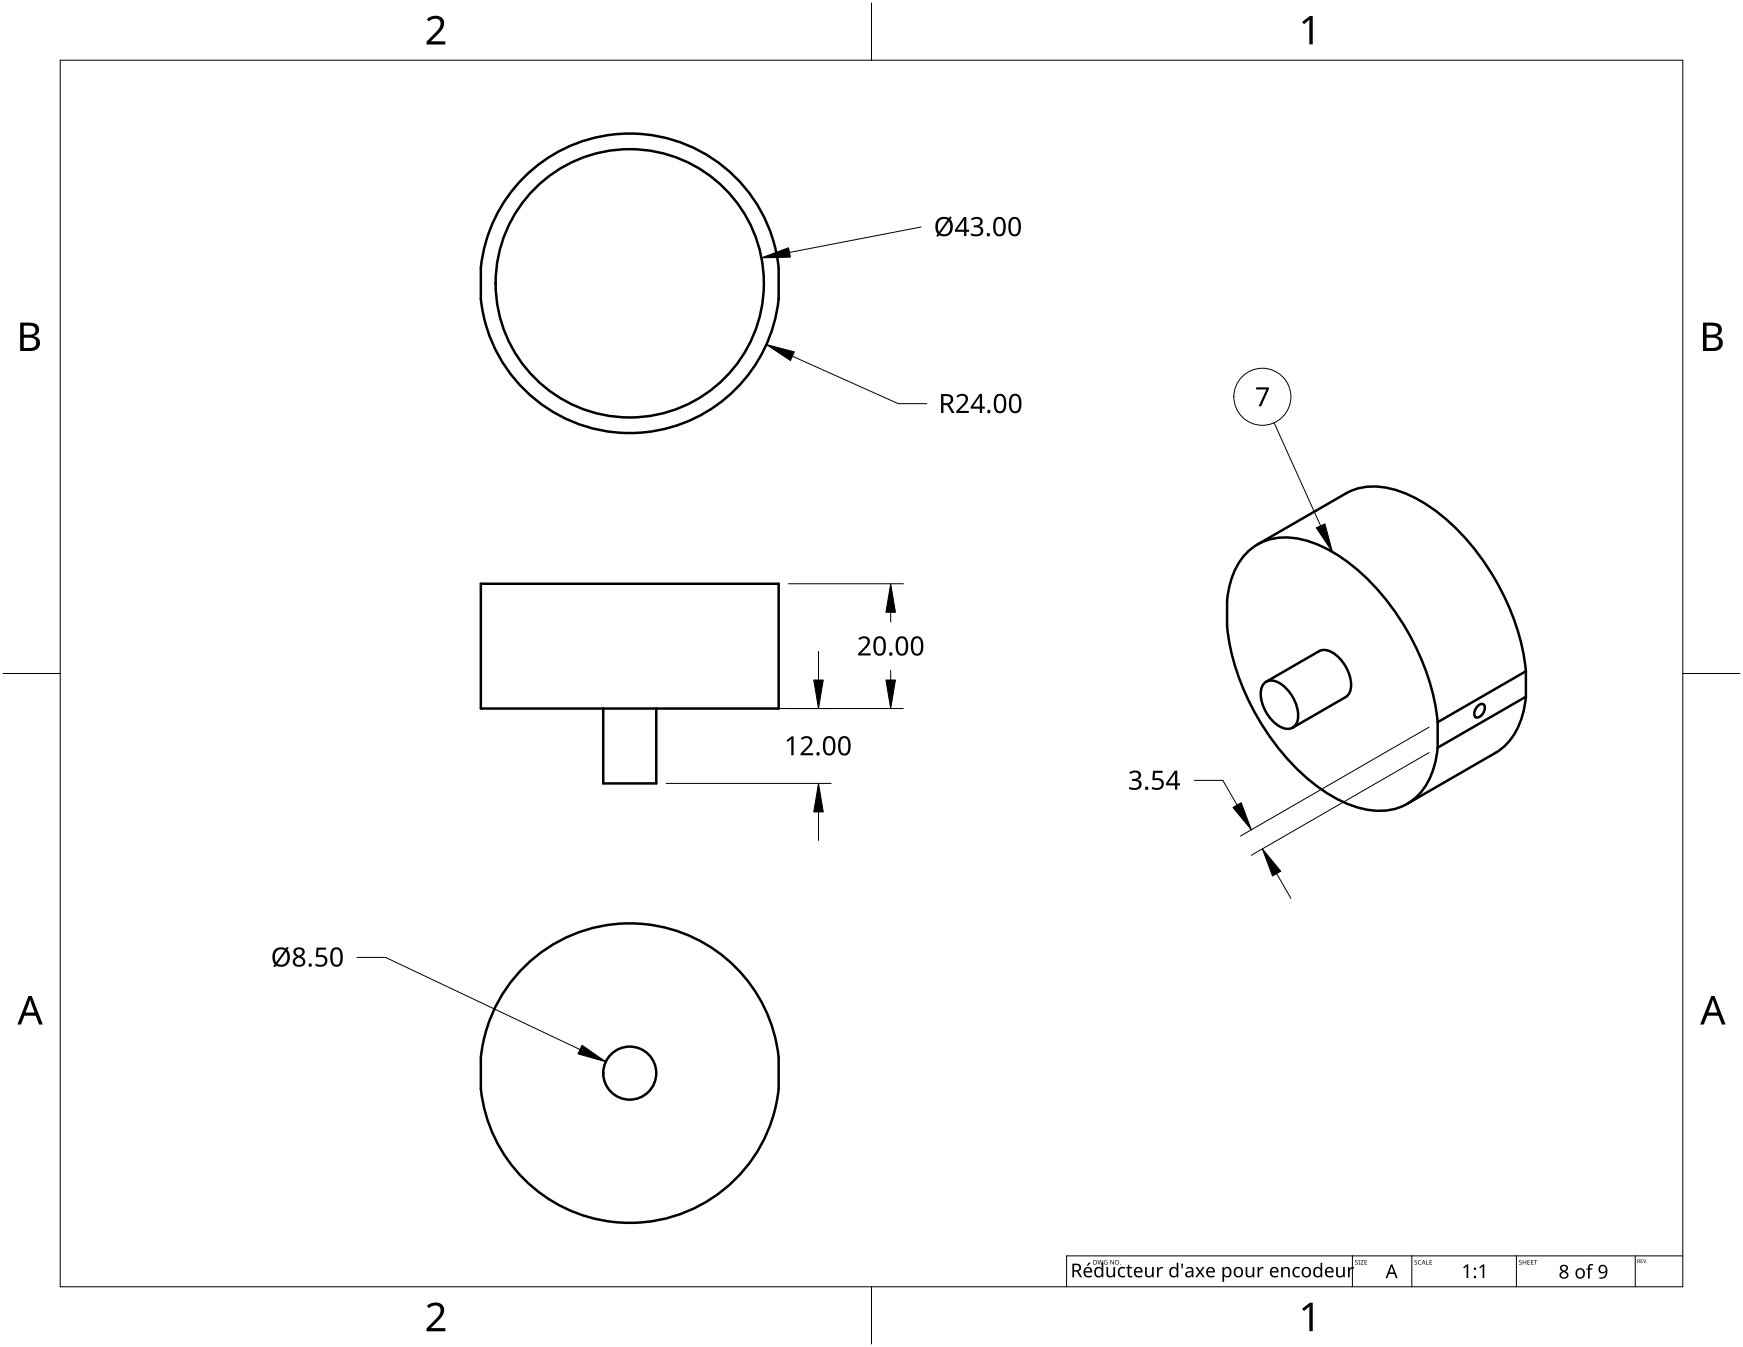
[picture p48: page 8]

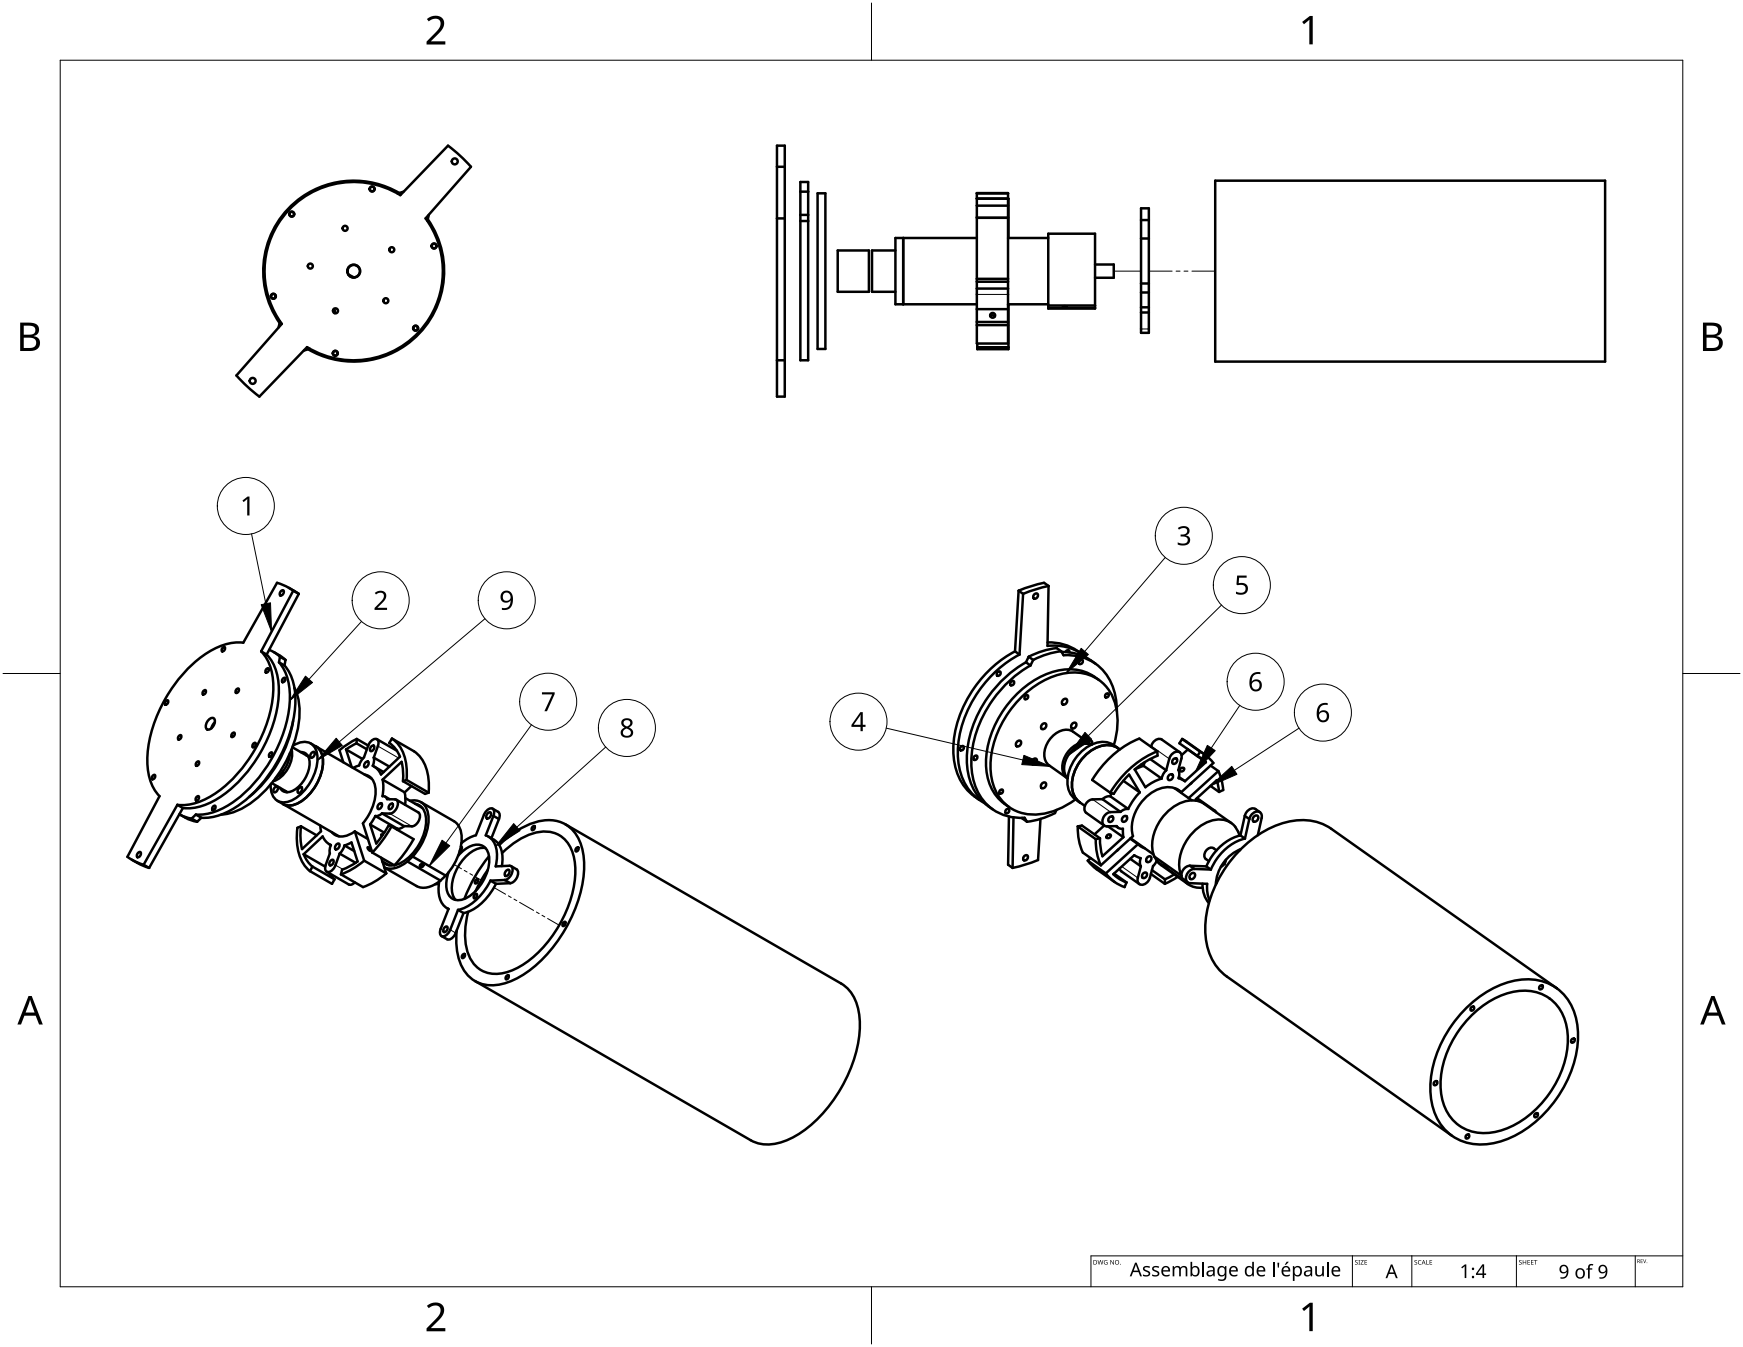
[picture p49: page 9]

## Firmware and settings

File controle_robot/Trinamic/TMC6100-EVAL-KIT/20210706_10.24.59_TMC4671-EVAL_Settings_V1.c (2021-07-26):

// use TMC4671 API
#include "hal/ic/TMC4671.h"

// Motor type &  PWM configuration
tmc4671_writeInt(0, TMC4671_MOTOR_TYPE_N_POLE_PAIRS, 0x00030008);
tmc4671_writeInt(0, TMC4671_PWM_POLARITIES, 0x00000000);
tmc4671_writeInt(0, TMC4671_PWM_MAXCNT, 0x00000F9F);
tmc4671_writeInt(0, TMC4671_PWM_BBM_H_BBM_L, 0x00001919);
tmc4671_writeInt(0, TMC4671_PWM_SV_CHOP, 0x00000007);

// ADC configuration
tmc4671_writeInt(0, TMC4671_ADC_I_SELECT, 0x09000100);
tmc4671_writeInt(0, TMC4671_dsADC_MCFG_B_MCFG_A, 0x00100010);
tmc4671_writeInt(0, TMC4671_dsADC_MCLK_A, 0x20000000);
tmc4671_writeInt(0, TMC4671_dsADC_MCLK_B, 0x00000000);
tmc4671_writeInt(0, TMC4671_dsADC_MDEC_B_MDEC_A, 0x014E014E);
tmc4671_writeInt(0, TMC4671_ADC_I0_SCALE_OFFSET, 0x01008001);
tmc4671_writeInt(0, TMC4671_ADC_I1_SCALE_OFFSET, 0x01008001);

// Open loop settings
tmc4671_writeInt(0, TMC4671_OPENLOOP_MODE, 0x00000000);
tmc4671_writeInt(0, TMC4671_OPENLOOP_ACCELERATION, 0x0000003C);
tmc4671_writeInt(0, TMC4671_OPENLOOP_VELOCITY_TARGET, 0xFFFFFFF6);

// Feedback selection
tmc4671_writeInt(0, TMC4671_PHI_E_SELECTION, 0x00000002);
tmc4671_writeInt(0, TMC4671_UQ_UD_EXT, 0x00000A60);

// ===== Open loop test drive =====

// Switch to open loop velocity mode
tmc4671_writeInt(0, TMC4671_MODE_RAMP_MODE_MOTION, 0x00000008);

// Rotate right
tmc4671_writeInt(0, TMC4671_OPENLOOP_VELOCITY_TARGET, 0x0000003C);
wait(2000);

// Rotate left
tmc4671_writeInt(0, TMC4671_OPENLOOP_VELOCITY_TARGET, 0xFFFFFFC4);
wait(4000);

// Stop
tmc4671_writeInt(0, TMC4671_OPENLOOP_VELOCITY_TARGET, 0x00000000);
wait(2000);
tmc4671_writeInt(0, TMC4671_UQ_UD_EXT, 0x00000000);

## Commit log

2021-07-26 Importe des paramètres à entrer dans l'IDE
2021-07-27 exemple de code essayé sur la raspberry
2021-07-28 image de l'epaule
2021-07-28 precision voltage
2021-08-23 Create stage août
